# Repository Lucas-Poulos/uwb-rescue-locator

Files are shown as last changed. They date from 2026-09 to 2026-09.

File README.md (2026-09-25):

# UWB Rescue Locator

Repo: https://github.com/Lucas-Poulos/uwb-rescue-locator

A two-board UWB positioning system for a rescue/safety use case: a
**wristband** worn by a person, and a fixed **bay station** that locates it
in 3D from four anchor points and reports it over Bluetooth LE to a nearby
laptop.

Positioning is a **hybrid of two-way ranging and TDoA**, not symmetric
multilateration. A center anchor ranges to the tag for distance; three outer
anchors timestamp the same tag transmission and give direction from the
arrival-time differences. The four anchors are **not interchangeable** --
see [`docs/positioning.md`](docs/positioning.md), which is the document to
read first if you're working on anchors, clocking, coax, or connectors.

## Getting started (new contributor setup)

### 1. Install KiCad

The team standard is **KiCad 10.0.5** (see Toolchain below for why).

- **macOS**: `brew install --cask kicad` (Homebrew). If KiCad is already
  installed some other way, add `--force` to overwrite it.
- **Windows/Linux**: download the installer for your platform from
  https://www.kicad.org/download/.

You do **not** need to set any environment variables or configure library
paths yourself -- both boards' `fp-lib-table`/`sym-lib-table` use
`${KIPRJMOD}`-relative paths into this repo's own `shared/` and `libs/`
folders, so cloning the repo anywhere and opening a project just works.

The very first time you launch the KiCad GUI on a given machine, it may
offer to set up its own default global libraries (Device, Connector, etc.)
-- accept the defaults. This is a one-time, per-machine, KiCad-level setup
step, unrelated to this repo.

### 2. Get repo access and clone it

Ask whoever's administering the repo to add you as a collaborator (repo
link at the top of this file), then:

```
git clone git@github.com:Lucas-Poulos/uwb-rescue-locator.git
cd uwb-rescue-locator
```

(Use the HTTPS clone URL instead if you haven't set up an SSH key with
GitHub.)

### 3. Open a board

KiCad doesn't support one project spanning multiple PCBs, so open whichever
board you're working on directly -- there's no single top-level project
file for the whole repo:

```
open wristband/wristband.kicad_pro       # macOS; or just double-click the file
open bay-station/bay-station.kicad_pro
```

### 4. Sanity-check your setup

From a terminal, **outside** this repo (see the `kicad-cli` gotcha further
down for why):

```
cd /tmp
kicad-cli sch erc /path/to/uwb-rescue-locator/wristband/wristband.kicad_sch
```

If this reports a handful of known/expected items (see each board's sheet
table below) rather than a wall of "library not included in configuration"
errors, your KiCad install is set up correctly. If you do see that wall of
errors, see the per-major-version global library table note in Toolchain.

Before pushing anything, also read `CONTRIBUTING.md` -- branch off `main`,
don't edit a sheet someone else is actively working on, and PRs need review
(branch protection is on).

## Status (last updated 2026-09-19)

**Schematic capture is in progress on both boards. Nothing is wired yet
except each board's own Power/BMS sheet.** If you're an agent or a new
teammate picking this up cold, read this whole section before touching
anything -- it's written to be a complete handoff.

> ### Architecture change in flight: the bay station's anchors
>
> The positioning scheme was specified properly for the first time on
> 2026-09-19 (`docs/positioning.md`), and it invalidates how the bay
> station's UWB anchors are currently drawn. **Target: 10-30 cm accuracy at
> ~10 m, on Channel 5 (6489.6 MHz).**
>
> What the schematic gets wrong today:
>
> 1. **The four anchors are drawn as interchangeable peers.** They aren't --
>    one is a center anchor doing two-way ranging, three are outer anchors
>    doing TDoA against it.
> 2. **The antennas are on the board.** TDoA bearing accuracy scales with
>    baseline; a board-sized baseline gives ~17 degrees of bearing error.
>    The four antennas move onto ~1-2 m coax runs to a rigid frame.
> 3. **The DWM3000 module can't do TDoA in a multi-anchor array at all.** It
>    exposes no clock pin, so four of them cannot share a time base -- and
>    1 ns of clock error is 30 cm of position error.
>
> **The resolved architecture:** four discrete **DW3210** ICs on the one PCB,
> sharing a single 38.4 MHz TCXO through a 1:4 low-skew buffer, with the four
> antennas remote on coax. This makes synchronization *structurally absent*
> rather than solved -- no drift model, no sync firmware -- and moves the cost
> into the RF path, where CH5's ~17 dB of link margin absorbs it.
>
> Going discrete adds an RF front-end and a controlled-impedance stackup. It
> also loses the module's pre-certified status -- which **does not matter
> here**: this is a university prototype, not marketed or sold, so it doesn't
> go through FCC/CE testing. That was the single largest cost of going
> discrete, and it's now off the table. See `docs/decisions.md`.
>
> The remaining critical-path item is **array calibration**, which the design
> genuinely does not close without.
>
> **The wristband is unaffected by the clock problem** -- a single transceiver
> has nothing to synchronize against. It has separately consolidated onto a
> single DWM3001C; see its own README.

### What exists, per board

The wristband has 7 hierarchical sheets, the bay station 10. Reference designators are
project-wide unique per board (checked, no collisions) -- see each
`libs/components.csv` for the full part-by-part BOM.

**Wristband** (`wristband/`):
| Sheet | Status | Contents |
|---|---|---|
| Power BMS | **Wired** (global labels, no drawn wires), ERC clean (0 errors, 1 cosmetic warning) | JST-PH battery -> AO3401A reverse-polarity FET -> TVS -> DW01A+FS8205A protection -> MCP73831 charger (USB-C in) |
| Radio MCU | Placement only, not wired | DWM3001C (U3) + decoupling. One module: DW3110 UWB + nRF52833 MCU + accelerometer + both antennas |
| Mechanical | Placement only | 4x M2 mounting holes |
| Regulation | Placement only, not wired | MCP1700T-3302E/TT LDO (3.3V) -- battery hits 4.2V, DWM3001C tops out at 3.6V |
| Programming/Debug | Placement only, not wired | ARM Cortex Debug SWD header, targeting the nRF52833 inside U3 |
| Indicators | Placement only | Status LEDs: D2 charge (MCP73831 STAT) + D3 system (nRF52833 GPIO) |
| Test Points | Placement only, **new** | TP1-TP5: both rails, 2x GND, firmware timing marker |

**Bay Station** (`bay-station/`):
| Sheet | Status | Contents |
|---|---|---|
| Power BMS | **Wired** (global labels), ERC has 8 known/expected items (see `power_bms_notes.md`) | Barrel jack + USB-C power-only input -> MCP73871 power-path charger -> MAX17048 fuel gauge; separate backup-battery input with its own AO3401A reverse-polarity FET + TVS |
| Connectivity | Placement only, not wired | Fanstel BT840 (U3, nRF52840) + decoupling. Symbol authored from the real datasheet |
| UWB Array | Placement only, not wired | 4x DW3210 (U4=A0 center, U5-U7=A1-A3 outer) + GPIO5/6 straps (R10-R17) + IRQ pulldowns (R25-R28) |
| Mechanical | Placement only | 4x M3 mounting holes |
| Regulation | Placement only, not wired | TPS62A02PDDCR buck converter -- steps the unregulated `+VSYS` rail down to a safe ~3.3V for the BT840 host and the DW3210 anchors |
| Clock Distribution | Placement only, **new** | Shared 38.4MHz reference for the 4x DW3210 array: AC-coupling + XTO caps placed, TCXO/buffer TBD |
| Indicators | Placement only | Status LEDs: D4 charging, D5 charge-done, D6 power-good (all MCP73871), D7 system (host GPIO) |
| Test Points | Placement only | TP1-TP14: rails, 2x GND, TCXO + 4x anchor clock, SPI, IRQ, reset |
| GNSS / Orientation | Placement only, **new** | MAX-M10S GNSS (U9) + LIS3MDL magnetometer (U10) + LIS2DH accelerometer (U11) -- georeferences the array |
| Programming/Debug | Placement only | **Rebuilt for Nordic**: SWD header (J3) + RESET button (SW2). ESP32 circuitry and the second USB-C deleted |

"Placement only" sheets deliberately show a lot of ERC "not connected"/"not
driven" warnings -- that's expected, not a bug, until they get wired.

### Confirmed chips/ICs (all sourced against real datasheets, not guessed)

| Part number | Role | Board(s) | Qty |
|---|---|---|---|
| Qorvo **DWM3001C** | UWB transceiver + nRF52833 MCU + LIS2DH12 accelerometer + both antennas, one module. Replaced NINA-B111 + DWM3000 + the antenna sheet | Wristband | 1 |
| Qorvo **DW3210** | Discrete UWB transceiver IC, QFN-40 5x5mm. One per anchor (U4=A0 center, U5-U7=A1-A3 outer). Chosen over the DWM3000 module because the module exposes no clock pin, and a shared reference is what makes the TDoA array work -- see `docs/positioning.md` | Bay Station | 4 |
| Qorvo **DWM3000** | UWB transceiver module. **No longer used on either board** -- the wristband moved to the DWM3001C and the bay station to discrete DW3210. Symbol and footprint are retained in `shared/` for reference only | -- | 0 |
| Microchip **MCP73831** | LiPo linear battery charger | Wristband | 1 |
| Fortune Semiconductor **DW01A** | Battery protection IC | Wristband | 1 |
| Fortune Semiconductor **FS8205** (commonly sold as "FS8205A" -- see `wristband/libs/README.md`) | Protection dual MOSFET, DW01A's partner IC | Wristband | 1 |
| AOS **AO3401A** | Reverse-battery-polarity protection P-MOSFET ("ideal diode") | Wristband + Bay Station | 2 |
| onsemi **ESD5B5.0ST1G** | TVS diode, battery/power-input protection | Wristband (1) + Bay Station (2) | 3 |
| Fanstel **BT840** (Nordic nRF52840) | Host MCU + BLE link to a laptop. Replaced ESP32-S3-WROOM-1 once the WiFi/internet requirement was dropped | Bay Station | 1 |
| Microchip **MCP73871** | Charge management + power-path IC | Bay Station | 1 |
| Maxim/Analog Devices **MAX17048** | Battery fuel gauge (SOC monitor) | Bay Station | 1 |
| Microchip **MCP1700T-3302E/TT** | LDO regulator (3.3V) -- battery rail can hit 4.2V, which exceeds the DWM3001C's 3.6V operating max without this | Wristband | 1 |
| TI **TPS62A02PDDCR** | Buck (switching) regulator -- same voltage-safety role as the wristband's LDO, sized for the bay station's higher combined load current | Bay Station | 1 |

Footprint caveats: MAX17048 is flagged `_PLACEHOLDER` in its footprint file
-- pin/electrical data is fully verified, but one land-pattern dimension
needs re-checking against the real datasheet figure before fab (see
`bay-station/libs/README.md`). The same caveat applies to the DWM3000
footprint retained in `shared/`, though nothing uses it now.

**No footprint assigned yet**: `U3` on both boards (BT840, 65 pins; and
DWM3001C, 48 pins), plus bay-station `L1` (1uH inductor -- no exact KiCad
default matches the XGL3520, pick at BOM time) and `SW2`. Not blocking
while both `.kicad_pcb` files are still empty, but it blocks layout.

Standard passive size for this whole project: **0603** for R/C/L (0-ohm
0603 link/jumper resistors are documented as a standard available option in
each `components.csv`, not yet placed on any sheet -- no specific
strap/bridge need identified yet).

Full reasoning/history for every choice above, plus the still-open
decisions (anchor placement, uplink backend, etc.), is in
`docs/decisions.md`.

### Known gotchas for whoever (human or agent) works on this next

- **kicad-cli silently fails on `extends`-based symbols.** Any cached
  schematic symbol using KiCad's `extends` mechanism (e.g. the default
  `AO3401A extends TP0610T`) makes `kicad-cli` fail to load the *entire
  file* and silently report it as empty (0 components, 0 ERC violations)
  rather than erroring loudly. Both boards work around this by embedding a
  flattened, non-`extends` copy of AO3401A. If a future sheet adds another
  `extends`-based part and ERC suspiciously shows 0 violations, check this
  first.
- **Always run `kicad-cli` from a scratch directory, never from inside a
  git repo.** It writes `.rpt` report files to the current working
  directory as a side effect; running it from inside a repo pollutes that
  repo's working tree with stray files.
- **KiCad's global library table is per-major-version and doesn't
  auto-populate from `kicad-cli` alone** -- see the Toolchain section below.
- **Don't leave a KiCad GUI window open on a project while also editing its
  files by hand/via script.** This happened once already: a background GUI
  session silently resaved `bay-station/power_bms.kicad_sch` in KiCad 10
  format while a concurrent edit was adding new sheets to the root file. No
  data was lost (verified via a reference-designator diff before
  committing), but it could have silently clobbered the newer edits if the
  stale window had been saved again afterward. Close/reload any open KiCad
  windows before doing further programmatic edits, and vice versa.
- The sibling project at `~/kicad-projects/wristband-alarm` (a *different*,
  unrelated wristband-alarm concept, also u-blox NINA-based) has its own
  long-standing uncommitted working-tree state -- don't touch it, don't
  assume its README reflects its actual working tree.

### Not done yet (in rough next-up order)

1. **Bay station: rework the anchor design** for four discrete DW3210s on
   one board sharing a TCXO, with the antennas on coax. Blocked behind the
   open items in `docs/decisions.md` (cable loss, TCXO/buffer selection,
   array calibration) -- this is the project's critical path.
2. Wire all placement-only sheets (net labels between MCU/radio pins, their
   decoupling, the new regulator outputs, and power-rail connections in
   from Power BMS). The wristband can proceed independently of item 1.
3. ~~**Bay station: resolve the two-USB-C-connector situation**~~ -- resolved
   by the move to Nordic. The second connector existed only for ESP32-S3
   native-USB flashing; the BT840 programs over SWD, so it goes away with the
   rest of the ESP32-specific circuitry.
4. **Bay station: source a real footprint for L1** (the buck converter's
   inductor, Coilcraft XGL3520-102MEC) -- no KiCad-default match exists yet.
5. ~~Confirm/re-verify decoupling cap values against each part's exact
   datasheet application circuit~~ -- done, see `docs/passives-reference.md`.
   One passive was found missing (100k IRQ/GPIO8 pulldowns, now added to all
   5 DWM3000 instances); DWM3000's own decoupling was confirmed to exceed
   what Qorvo's minimal example circuit actually calls for (kept anyway, not
   wrong, just more conservative than strictly required).
6. ~~Antenna matching-network values~~ -- gone. The DWM3001C carries both
   antennas on-module, so `antenna.kicad_sch` was deleted along with the
   tuning task.
7. ~~Anchor placement/enclosure geometry~~ -- topology resolved (all four
   transceivers on-board, antennas remote on coax to a rigid frame, see
   `docs/positioning.md`); the remaining piece is the frame's mechanical
   design, including A0's out-of-plane offset.
8. Bay station uplink protocol -- what the laptop actually receives over BLE
   (open decision). "Backend" no longer applies: there is no server, see
   `docs/system-overview.md`.
9. PCB layout. The bay station's `.kicad_pcb` now has its **4-layer
   controlled-impedance stackup** set from DW3000 Section 7.3.2 Figure 35
   (1.048mm finished) -- but nothing else: no footprints, no outline. The
   wristband's is still an empty stub. The blocker is upstream of layout:
   both boards are placement-only, so there are **zero nets** to import.

## System overview

```
                         A1 ← antenna on coax
                            \
   ┌─────────────┐           \      ┌───────────────────────────┐
   │  Wristband   │  UWB       ○────│  Bay Station (ONE PCB)     │
   │  (worn tag)  │ ═════════▶ A0   │  4x DW3210, one TCXO       │
   └─────────────┘  one TX    / \   │  BT840 (nRF52840) host     │
                             /   \  └───────────┬────────────────┘
                           A2     A3            │ Bluetooth LE
                      antennas on ~1-2 m        ▼
                      coax, rigid frame       Laptop

   A0     two-way ranging  -> range to tag
   A1-A3  TDoA vs. A0      -> direction to tag

   All four transceivers share one clock on the board.
   Only the antennas are remote.
```

- **Wristband**: one Qorvo DWM3001C (UWB + nRF52833 MCU + antennas) +
  a compact BMS (MCP73831 charger + DW01A/FS8205 protection + AO3401A
  reverse-polarity protection). Design compromises favor small size and
  just enough battery life to get core functionality working. In the
  positioning scheme its job is simply to transmit -- one transmission
  yields all four measurements, deliberately, because the tag is the
  power-constrained side.
- **Bay station**: four UWB receivers in two roles (one center, three outer)
  on a single PCB sharing one TCXO + a Fanstel BT840 (nRF52840) host, linking
  to a laptop over BLE + a BMS designed for long runtime rather than small size
  (MCP73871 power-path charger + MAX17048 fuel gauge), since the bay station
  isn't worn. The four antennas sit on ~1-2 m coax runs to a rigid frame --
  that's what buys the baseline the bearing measurement needs.

There's no physical connector between the wristband and the bay station --
their only interface is the UWB radio link. The bay station's own antennas
are wired to it over SMA coax (CH5 at 6489.6 MHz is above U.FL's 6 GHz
rating). See `docs/system-overview.md` and `docs/positioning.md`.

## Repo layout

```
shared/                      # symbols/footprints/3D models used on BOTH boards (e.g. the UWB IC)
  symbols/                   # shared .kicad_sym library
  footprints/                # shared .pretty footprint library
  3dmodels/                  # shared .step/.wrl models
wristband/                   # KiCad project: the wearable tag
  wristband.kicad_pro/sch/pcb
  libs/                      # wristband-only symbols/footprints
bay-station/                 # KiCad project: the fixed 4-anchor station
  bay-station.kicad_pro/sch/pcb
  libs/                      # bay-station-only symbols/footprints
docs/
  positioning.md             # the ToF + TDoA scheme, error budget, clock architecture
  system-overview.md         # block diagram + RF/data interface between the boards
  decisions.md               # open + resolved component/architecture decisions log
  passives-reference.md      # every chip's reference-design passives, compiled per-chip
  bom-cost.md                # build cost estimate for one prototype pair
firmware/                    # nRF52840 / nRF52833 firmware -- skeleton only, nothing written
CLAUDE.md                    # working rules for Claude Code / other coding agents
CONTRIBUTING.md              # git workflow, sheet conventions, pre-push checks
```

Each board is its own KiCad project (KiCad doesn't support one project
spanning multiple PCBs), but both live in this one repo so shared parts,
docs, and history stay in one place. Each project's `fp-lib-table` /
`sym-lib-table` reference the `shared/` libraries via `${KIPRJMOD}` relative
paths, so this works regardless of where the repo is cloned -- no per-machine
setup needed.

## Toolchain

Files are currently in **KiCad 8.0** format, originally authored/verified
against KiCad 8.0.6. As of 2026-08-14 this machine has been upgraded to
**KiCad 10.0.5** (the actual current stable -- confirmed as the team's
standard, superseding an earlier, since-corrected plan to target KiCad 9.x).
All existing files were re-checked with
`kicad-cli` under 10.0.5 (`sch erc`/`pcb drc`) and open/parse cleanly with no
new issues -- opening a file in the newer GUI and re-saving is still a
one-way, zero-cost upgrade whenever the team wants to bump the file format
itself; nothing has been re-saved yet, so the files on disk are still 8.0
format.

Note for anyone else upgrading KiCad's major version: `kicad-cli` alone
won't auto-populate the new version's global symbol/footprint library table
(`~/Library/Preferences/kicad/<version>/sym-lib-table` /`fp-lib-table`) --
that normally happens the first time you launch the actual KiCad GUI and it
offers to migrate/create settings. If you only ever use `kicad-cli`
headlessly without opening the GUI first, you may see a wall of spurious
"library not included in configuration" ERC errors -- just launch KiCad.app
once (or copy the two `*-lib-table` files from
`.../KiCad.app/Contents/SharedSupport/template/`) to fix it.

## Using Claude Code (or another coding agent) on this project

**The working rules for agents live in [`CLAUDE.md`](CLAUDE.md)** -- Claude
Code picks that up automatically. This section is the human-readable version
of why those rules exist.

KiCad's file formats (`.kicad_sch`, `.kicad_pcb`, `.kicad_pro`, `.kicad_sym`,
`.kicad_mod`) are plain text (S-expression or JSON) -- an agent can read and
edit them directly like any other source file, no special MCP server or
plugin required. Everything in this repo so far was built that way. A few
things make it work reliably, several of them learned the hard way in this
repo's own history:

- **`kicad-cli` is the fast headless sanity check.** After any edit, run
  `kicad-cli sch erc <board>.kicad_sch` and `kicad-cli pcb drc
  <board>.kicad_pcb` before trusting a change.
  - **macOS**: a Homebrew install symlinks it onto `PATH` automatically
    (`/opt/homebrew/bin/kicad-cli`); otherwise it's inside the app bundle at
    `/Applications/KiCad/KiCad.app/Contents/MacOS/kicad-cli`.
  - **Windows**: the official installer puts it on `PATH` automatically; if
    not, it's at `C:\Program Files\KiCad\10.0\bin\kicad-cli.exe`.
  - **Linux**: on `PATH` automatically via most package managers (apt,
    dnf, etc.) or the official AppImage/flatpak.
- **Always run `kicad-cli` from a scratch/temp directory, never from
  inside this repo.** It writes `.rpt` report files to the current working
  directory as a side effect -- running it from inside a git repo (this
  one or any other) pollutes the working tree with stray files. This has
  actually happened once already, to an unrelated sibling project, from a
  leftover `cd`.
- **`kicad-cli` silently fails on `extends`-based symbols.** A cached
  schematic symbol using KiCad's `extends` mechanism (e.g. the default
  library's `AO3401A extends TP0610T`) makes `kicad-cli` fail to load the
  *entire file* and report it as empty (0 components, 0 ERC violations)
  instead of erroring loudly -- a suspiciously clean ERC run is a red flag,
  not necessarily good news. This repo works around it everywhere by
  embedding flattened, non-`extends` copies of any such symbols (see
  `docs/decisions.md` and the various `*_notes.md` files for examples).
- **Use an existing sheet/symbol/footprint as the format template before
  writing a new one.** Every file in this repo was built by reading a
  known-good file first -- either one already in this repo, or one of
  KiCad's own bundled default libraries -- and matching its exact
  structure, rather than freehand-authoring the s-expression format from
  memory. This repo uses literal tab characters for indentation, not
  spaces; match that.
- **Don't run scripted file edits at the same time as a live KiCad GUI
  session has the same project open.** A background GUI window doesn't
  know about changes made outside it, and saving from a stale window can
  silently overwrite newer edits -- this already caused one near-miss on
  the bay station board (see "Known gotchas" above). Close/reload any open
  KiCad windows before scripted edits, and vice versa. A lock file at
  `<board>/~<board>.kicad_pro.lck` means a GUI session currently has that
  project open.
- **Verify real datasheet facts (pinouts, voltage ratings, current draw)
  by actually fetching and reading the datasheet PDF**, not from memory or
  a search-result summary -- several real bugs/gaps in this repo were only
  caught this way (e.g. the wristband's missing voltage regulator, a
  part-number that doesn't actually exist, a mislabeled SOT-23-6 part).
- **pcbnew's Python bindings** are available for programmatic
  footprint/board work (generating a blank `.kicad_pcb`, loading a
  footprint to sanity-check its pad count, etc.) via KiCad's own bundled
  Python interpreter -- **not** your system Python, which won't have the
  `pcbnew` module installed:
  - **macOS**: `/Applications/KiCad/KiCad.app/Contents/Frameworks/Python.framework/Versions/Current/bin/python3`
  - **Windows**: typically `C:\Program Files\KiCad\10.0\bin\python.exe`
  - **Linux**: usually just your system `python3` if KiCad was installed via
    a package manager that wires up the `pcbnew` module for it; otherwise
    check your distro's KiCad packaging docs.

## Will this work on both Mac and Windows?

Yes, and this has actually been checked, not just assumed:

- No absolute Mac-specific paths are baked into any `.kicad_pro`/`.kicad_sch`/
  `.kicad_pcb`/library file (`git grep`-checked) -- all cross-file/library
  references use `${KIPRJMOD}`-relative paths, which KiCad resolves
  identically on every OS.
- No filenames in this repo use characters or reserved names that are
  illegal on Windows (`: * ? " < > |`, or `CON`/`PRN`/`AUX`/`NUL`/`COM1-9`/
  `LPT1-9`), and no path exceeds even a fraction of Windows' historical
  260-character path limit (longest path in this repo is 80 characters).
- All tracked files use consistent LF line endings, and `.gitattributes`
  normalizes this going forward so a Windows contributor's git config
  (which sometimes auto-converts line endings on checkout) can't silently
  turn KiCad files into CRLF and create noisy diffs or merge pain.

What differs by platform is purely the install step and a couple of tool
paths (both covered above/in Getting Started) -- KiCad itself, the file
formats, and this repo's structure are fully cross-platform.

## Contributing

See `CONTRIBUTING.md` for the git workflow (branching, hierarchical-sheet
conventions to avoid merge conflicts, pre-push checks).

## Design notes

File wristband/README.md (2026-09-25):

# Wristband

The worn tag. Open `wristband.kicad_pro` in KiCad.

## Scope

Deliberately minimal: **battery management plus one UWB module, and not much
else.** The tag's only job is to take part in a two-way ranging exchange with
the bay station's center anchor. Everything not needed for that is gone.

- **UWB + MCU**: Qorvo **DWM3001C** (resolved 2026-09-19) -- one module
  containing the DW3110 UWB transceiver, a Nordic nRF52833 MCU, an ST
  LIS2DH12 accelerometer, the UWB and Bluetooth antennas, power management
  and the 38.4 MHz crystal. Its datasheet states it *"requires no RF design
  as the antenna and associated analog and RF components are on the module"*.
- **BLE and the accelerometer are unused.** The tag talks only over UWB. Both
  are silicon inside a module bought for its Cortex-M4 and its UWB radio --
  they cost nothing to leave idle: no external parts, no wiring, no firmware.
  See "Worth revisiting" below.
- **BMS**: sized for "just enough" runtime -- size and weight take priority
  over battery life here, in contrast with the bay station.

Why the tag transmits once per fix: the bay station's center anchor completes
the ranging exchange, and the three outer anchors timestamp that *same*
transmission. One transmission, four measurements -- deliberately, because
the tag is the power-constrained side. See `../docs/positioning.md`.

## Status

Seven hierarchical sheets, all registered in `wristband.kicad_pro`'s `sheets`
list and wired into `wristband.kicad_sch` as sheet symbols.

| Sheet | Status | Contents |
|---|---|---|
| `power_bms` | **Wired** (global labels, no drawn wires), ERC clean | Full battery/charging/protection chain |
| `radio_mcu` | **Wired**, ERC clean | DWM3001C (U4) + decoupling; SWD, RESET_N, SWO, VBAT_SENSE, SOS button |
| `regulation` | **Wired**, ERC clean | TPS7A0233PDBVR LDO -> 3.3V (U5) |
| `programming_debug` | **Wired**, ERC clean | ARM Cortex Debug SWD header |
| `indicators` | Placement only -- **8 ERC errors** (unconnected pins) | Status LEDs D2 (charge) + D3 (system) |
| `testpoints` | Placement only -- **5 ERC errors** (unconnected pins) | TP1-TP5: both rails, 2x GND, firmware timing marker |
| `mechanical` | Placement only | 4x M2 mounting holes |

**"Placement only" means components are instantiated and laid out, but
nothing is wired** -- no drawn wires, no global labels, no net identity.

`indicators` and `testpoints` are the two sheets still in that state. They
came across from the positioning-architecture redesign on `main`, where they
were never wired, and they account for all 13 of the wristband's remaining
ERC errors. Everything else on this board is wired and ERC clean.

**ERC, run 2026-09-19 with kicad-cli 10.0.6: 104 violations, ZERO errors.**
All warnings, and all the expected unwired-sheet state: 80 pin_not_connected,
10 power_pin_not_driven, 3 pin_not_driven, plus 11 lib_symbol_mismatch from
the embedded 8.0-format symbol copies differing from the 10.x libraries
(pre-existing and by design -- see the flattened-copy workaround in
`../CLAUDE.md`). DRC reports one violation per board, `invalid_outline`,
because no board outline is drawn yet.

### Sheet detail

- **`power_bms.kicad_sch`** -- the complete battery chain: 2-pin JST-PH
  battery input (`BT1`); AO3401A P-MOSFET reverse-polarity "ideal diode"
  (`Q1`, `R1`); battery-rail TVS ESD5B5.0ST1G (`D1`); DW01A + FS8205A
  single-cell overcharge/overdischarge/overcurrent protection wired per
  Fortune Semiconductor's own DW01A typical application circuit (`U1`, `Q2`,
  `R2`, `R3`, `C1`); MCP73831 Li-Po charger with power-only USB-C input, PROG
  resistor sized for ~147mA charge current, and datasheet-recommended
  input/output caps (`U2`, `J1`, `R4`, `C2`, `C3`, `R5`, `R6`); bulk/bypass
  decoupling on the protected `VBAT` rail (`C4`, `C5`).

  Net identity is carried entirely by global labels placed on top of each
  pin. ERC: 0 errors, 1 harmless documented warning. Full rationale in
  `power_bms_notes.md`.

- **`radio_mcu.kicad_sch`** -- one `wristband:DWM3001C` (`U4`) plus VDD
  decoupling (`C6` 100nF, `C7` 10uF). Now wired: SWD (`SWDCLK`/`SWDIO`/
  `SWO`), `RESET_N`, `VBAT_SENSE` on P0.02/AIN0, and the SOS button on
  P0.17. 12 of the module's 48 pins are tied; the rest await the pin
  assignments still open in `../docs/decisions.md`.

  Pin data verified against the real Qorvo DWM3001C Data Sheet Rev B (May
  2022), Table 2. One caveat carried in the symbol: **pin 18 is not
  documented in that table** (it lists 1-17 and 19-48), so it is modelled as
  a passive NC and needs confirming against the land-pattern figure.

  Decoupling values are conservative standard practice, *not*
  datasheet-specified -- the module has on-board power management and Qorvo
  publishes no external application circuit for it.

  Two real layout requirements are recorded in the sheet's own notes: the
  **10 mm antenna keep-out** (Section 7.1) and **keeping the module at least
  1 cm from the PCB edge** (Section 7.2), which reduces the horizontally
  polarized radiation component and improves multipath resilience.

- **`regulation.kicad_sch`** -- TI **TPS7A0233PDBVR** LDO (`U5`, SOT-23-5,
  3.3V fixed, 200mA, 25nA typ Iq) steps the protected `VBAT` rail (up to
  4.2V at full charge) down to `+3V3`. Replaced the MCP1700T-3302E/TT on
  2026-09-23, whose 1.6uA Iq had become the board's largest standby draw --
  see `../docs/decisions.md`. Still required: the DWM3001C's operating
  maximum is 3.6V (Table 4), well under a full battery. **EN must be tied
  high**; the part is disabled when EN floats. See `regulation_notes.md`.

- **`programming_debug.kicad_sch`** -- ARM Cortex Debug SWD connector (`J3`,
  `Connector:Conn_ARM_JTAG_SWD_10`, 2x5 1.27mm). Now targets the nRF52833
  inside U3, via `SWD_CLK` (pin 2) and `SWD_DIO` (pin 3).

- **`indicators.kicad_sch`** -- status LEDs. `D2`/`R10` is charge status from
  MCP73831 `STAT` (U2 pin 1, `power_bms.kicad_sch`). `D3`/`R11` is system
  status on an nRF52833 GPIO. 0603 parts, indicative 1k series resistors,
  low-current by design since the tag runs off a small cell.

- **`testpoints.kicad_sch`** *(new)* -- `TP1` +3V3, `TP2` VBAT, `TP3`/`TP4`
  ground, `TP5` a firmware timing marker on a spare nRF52833 GPIO so tag-side
  exchange timing is visible on a scope. Deliberately minimal: the DWM3001C's
  internals are unreachable and SWD already comes out on `J3`. `TP2` matters
  because there is no power switch -- it is the only way to check the battery
  chain without disconnecting the cell.

- **`mechanical.kicad_sch`** -- 4x M2 mounting holes (`H1`-`H4`).

### Next up

1. **Get U3's footprint.** Do not hand-author it -- import from a vendor
   library. Qorvo supplies DWM3001C footprint/symbol files (Altium format)
   via their UWB tech forum, and SnapMagic/SnapEDA lists a Qorvo-provided
   set. Check pad naming matches this symbol's 1-48 numbering. Blocks layout.
2. Wire the six placement-only sheets: the `VBAT` -> `+3V3` rail handoff,
   SWD to U3, the LED drives. There is no MCU-to-transceiver SPI to wire any
   more -- that link is inside the module.

### Worth revisiting

**Motion-gating the UWB.** The LIS2DH12 accelerometer inside the DWM3001C is
unused, but the tag is the power-constrained side of the whole system. Only
ranging when the wearer actually moves is the largest battery lever available
and costs nothing in hardware -- the accelerometer is already on the module's
I2C bus (pins 14/15). Worth doing once basic ranging works.

## Libraries

- `libs/` -- wristband-only symbols/footprints, including the hand-authored
  `DWM3001C` symbol
- `../shared/` -- still registered via `fp-lib-table`/`sym-lib-table`, but
  this board no longer uses anything from it (see `../shared/README.md`)

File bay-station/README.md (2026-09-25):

# Bay Station

The fixed reference station. Open `bay-station.kicad_pro` in KiCad.

## Scope

- **UWB anchors**: four DW3210 transceivers, all on this PCB sharing one
  38.4 MHz TCXO, in two distinct roles -- one **center** anchor (A0) that
  does two-way ranging with the wristband, and three **outer** anchors that
  measure TDoA against it. Range plus direction gives a 3D fix. The four
  **antennas** are remote, on ~1-2 m SMA coax runs to a rigid frame. Read
  `../docs/positioning.md` before touching anything in the anchor, clock,
  coax, or connector path.
- **Host MCU + link**: Fanstel **BT840** (Nordic nRF52840, resolved
  2026-09-19) -- drives the four DW3210s and reports position over **BLE to a
  nearby laptop**. There is no internet uplink; that was dropped deliberately,
  and dropping it is what allowed the move off the ESP32-S3 to Nordic. See
  `../docs/decisions.md`.
- **BMS**: optimized for longevity rather than size, since this board isn't
  worn (contrast with the wristband's compromise-heavy BMS).

Target performance: **10-30 cm at ~10 m, on Channel 5 (6489.6 MHz)**.

> **Schematic capture is done for the anchor array; layout is not.** Four
> discrete DW3210s share one TCXO through a 1:4 low-skew buffer, with the
> antennas on ~1-2 m coax. What remains before layout: footprints for the
> BT840 and the DW3210 exposed pad, TCXO and buffer part selection, and the
> anchor decoupling, which must be re-derived for a bare IC rather than
> reused from the module.
>
> **Array calibration is a deliverable, not a bring-up nicety** -- the design
> does not meet its accuracy target without it. See `../docs/decisions.md`.

## Status

Ten hierarchical sheets, all registered in `bay-station.kicad_pro`'s
`sheets` list and wired into `bay-station.kicad_sch` as sheet symbols.

| Sheet | Status | Contents |
|---|---|---|
| `power_bms` | **Wired** (global labels), 8 known/expected ERC items | Barrel jack + USB-C in -> MCP73871 power-path -> MAX17048 gauge |
| `connectivity` | Placement only | **BT840 (U3) placed** + C5/C6/C7 decoupling. Symbol authored; footprint still needed |
| `uwb_array` | Placement only | **4x DW3210 placed** (U4=A0 center, U5-U7=A1-A3 outer) + R10-R17 straps + R25-R28 IRQ pulldowns |
| `regulation` | Placement only | TPS62A02PDDCR buck -> +3V3_SYS |
| `programming_debug` | Placement only | **Rebuilt for Nordic**: SWD header (J3) + RESET button (SW2). ESP32 circuitry and the second USB-C deleted |
| `clock_dist` | Placement only, **new** | Shared 38.4MHz reference: AC-coupling + XTO caps placed, TCXO/buffer TBD |
| `indicators` | Placement only, **new** | Status LEDs D4-D7 (charge, charge-done, power-good, system) |
| `testpoints` | Placement only, **new** | TP1-TP14: rails, 2x GND, TCXO + 4x anchor clock, SPI, IRQ, reset |
| `gnss` | Placement only, **new** | MAX-M10S GNSS (U9) + LIS3MDL magnetometer (U10) + LIS2DH accelerometer (U11) |
| `mechanical` | Placement only | 4x M3 mounting holes |

**"Placement only" means components are instantiated but nothing is wired**
-- no wires, no global labels.

**ERC, re-run 2026-09-23 with kicad-cli 10.0.6: 518 violations, ZERO errors.**
All warnings: 360 pin_not_connected, 98 power_pin_not_driven, 36
pin_not_driven, 9 lib_symbol_mismatch, 8 ground_pin_not_ground (the DW3210
VSS pins, which resolve once grounds are wired), 6 isolated_pin_label (the
MCP73871 status outputs, which `indicators` will terminate), and 1
lib_symbol_issues on U8 -- investigated and deliberately left alone, see
`../docs/decisions.md`. DRC reports one `invalid_outline`, because no board
outline is drawn yet.

### The PCB

`bay-station.kicad_pcb` now carries the **4-layer controlled-impedance
stackup** (F.Cu / prepreg 254um / In1.Cu / core 400um / In2.Cu / prepreg
254um / B.Cu, 35um copper throughout, 1.048mm finished), taken from DW3000
Datasheet v1.3 Section 7.3.2 Figure 35. Until 2026-09-23 the file was an
empty 2-layer default stub, which contradicted a decision the docs had
already recorded as settled. The rest of Section 7.3 -- 50 ohm RF1/RF2,
ground cutouts under each DW3210, group separation -- is written as a note
on the board's `Cmts.User` layer, where layout will actually see it.

The dielectric numbers (er 4.5, tan d 0.02) are KiCad's FR4 defaults, not
datasheet values. Controlled impedance means the fab's stackup wins.

**Nothing else is on the board.** No footprints are placed and no outline is
drawn, and neither is worth doing yet: every sheet is still placement-only,
so `kicad-cli sch export netlist` returns **zero nets**. Importing footprints
now would give an unconnected pile with no ratsnest to place against. Wire
the sheets first.

Three parts also could not be placed even if it were wired, because they
have no footprint assigned: **L1** (no exact KiCad match for the Coilcraft
XGL3520), **U3** (BT840, awaiting a vendor import) and **SW2** (RESET button,
never assigned one -- newly found). See `../docs/decisions.md`.

### Sheet detail

- **`power_bms.kicad_sch`** -- external power input via DC barrel jack
  (`Connector:Barrel_Jack`, series Schottky reverse-polarity diode) and a
  power-only USB-C receptacle (`Connector:USB_C_Receptacle_PowerOnly_6P`,
  CC1/CC2 5.1k pulldowns), both feeding a shared `+5V_IN` net with its own
  TVS. Backup Li-Ion cell gets an AO3401A P-MOSFET reverse-polarity "ideal
  diode" plus its own TVS. MCP73871 charge-management/power-path IC wired per
  Microchip's typical application circuit (DS20002090E) in
  AC-DC-adapter/power-path mode (SEL=high), PROG1/PROG3 set for a 500mA
  fast-charge / 50mA termination profile, plus the VPCC power-path-priority
  divider, THERM NTC, and IN/OUT/VBAT decoupling. MAX17048 fuel gauge
  (`bay_station:MAX17048G+T10`) with VDD decoupling, CTG/QSTRT tied per
  datasheet, ALRT/SCL/SDA brought out via global labels.

  ERC-clean except one deliberately-deferred finding (MAX17048 SCL has no
  driver until the I2C host on `connectivity` is wired). See
  `power_bms_notes.md`.

- **`connectivity.kicad_sch`** -- Fanstel **BT840** (`U3`, nRF52840) plus
  `C5`/`C6`/`C7` supply decoupling. Symbol hand-authored: all 65 pins (16
  castellated, 49 LGA) from the real Fanstel datasheet Ver 1.15 Pin Function
  table. GND verified on 10/A0/B0/C0/D0/F0-F3, VDD on 9.

  The sheet notes carry what the wiring pass needs: use **SPIM3** for the
  anchor bus (the only high-speed SPI instance on the nRF52840), and avoid
  B4/B5/C3/D2 if the design might ever move to a BT840X/XE, where those are
  PA-control pins.

  Footprint still outstanding, and the datasheet contradicts itself on LGA
  count (summary says 45, its own table lists 49) -- reconcile both against
  the mechanical drawing.

- **`uwb_array.kicad_sch`** -- **four DW3210s**, `U4`-`U7`, labelled A0-A3 on the sheet. `U4` is
  the **center anchor** and does the two-way ranging; `U5`-`U7` are the outer
  anchors that timestamp the same transmission for TDoA. Symbol hand-authored
  from the real DW3000 Datasheet v1.3 Table 2.

  Kept from the module revision, because both survive the module-to-IC move
  unchanged (same DW3000 core) and both were datasheet-verified findings:
  - `R10`-`R17`, the 10k GPIO5/GPIO6 SPI-mode straps (two per anchor).
  - `R25`-`R28`, the 100k IRQ pull-downs from Qorvo Figure 11 -- a real gap
    the passives audit originally caught. Not losing it twice.

  Deleted with the modules: `C8`-`C19`. Those were sized for a single VDD3V3
  module rail and do not map onto a bare DW3210, which has VDD1 (pin 29, main
  + I/O), VDD2a/VDD2b (28/23) and VDD3 (26), **plus two decoupling-only pins**
  -- VTX_D (27) and VIO_D (38) -- that each need their own cap to ground and
  must not be tied to a rail. Decoupling is deliberately not yet placed;
  re-derive it from the IC datasheet at wiring time.

- **`regulation.kicad_sch`** -- TI `TPS62A02PDDCR` synchronous buck (`U8`,
  2.5-5.5V in / 2A, datasheet SLUSEG9E) stepping `+VSYS` down to `+3V3_SYS`.
  Chosen over the TPS563201/TPS563200 family specifically because its
  2.5-5.5V input range covers the single-cell-Li-Ion-only `+VSYS` condition
  that the 4.5V-minimum TPS563201 cannot. Includes the datasheet-recommended
  1uH inductor (`L1`), input/output caps (`C20`/`C21`), feedforward cap
  (`C22`), and feedback divider (`R8`=453k/`R9`=100k, targeting 3.318V).
  Budget re-run twice on 2026-09-19 and now ~347mA against the 2A rating
  (~5.8x) -- dropping WiFi removed the largest single load. Deliberately
  oversized and staying that way; see `regulation_notes.md`.

- **`programming_debug.kicad_sch`** *(rebuilt)* -- collapsed to what a Nordic
  part actually needs: `J3`, a 2x5 1.27mm ARM Cortex Debug SWD header, and
  `SW2`, the RESET button. Deliberately the **same debug connector as the
  wristband**, so one probe and one cable serve the whole project.

  Deleted as ESP32-specific: `R18`-`R21` (GPIO0/3/45/46 boot straps -- Nordic
  has no equivalent), `R22`+`C23` (EN reset RC -- the nRF52840 has internal
  POR), `SW1` (BOOT button -- no boot-mode pin), and `J3`+`R23`/`R24` (the
  data-capable USB-C, which existed only for ESP32-S3 native-USB flashing).

  **That last deletion resolves the two-USB-C open item** -- by removal
  rather than by choosing between connectors. The board is back to one USB-C:
  the power-only `J2` on `power_bms.kicad_sch`.

  Exact BT840 pin numbers for SWDIO/SWCLK/RESET are not filled in yet, for
  the same reason as `connectivity`.

- **`clock_dist.kicad_sch`** *(new)* -- the defining block of this board's
  architecture. Holds the shared 38.4 MHz reference network that makes TDoA
  across four receivers possible at all. Topology is TCXO -> 1:4 low-skew
  fan-out buffer -> 2200 pF AC coupling -> each DW3210's XTI, with 1 pF from
  each XTO to ground.

  Placed: `C24`-`C27` (2200 pF AC coupling) and `C28`-`C31` (1 pF XTO-to-GND)
  -- the passives whose values the DW3000 datasheet actually specifies. The
  **TCXO and buffer parts are not yet selected** (open item); the sheet
  carries the full Table 10 selection spec as an in-schematic note so
  whoever picks them has it to hand.

- **`indicators.kicad_sch`** *(new)* -- status LEDs. Before this sheet the
  bay station had no user-visible indication of any kind, which is a poor
  property for a device whose job is locating someone in trouble.
  `D4`/`R29` from MCP73871 `STAT1` (charging), `D5`/`R30` from `STAT2`
  (charge complete), `D6`/`R31` from `~PG` (external power good) -- all
  three charger outputs were previously unconnected -- plus `D7`/`R32` on an
  BT840 GPIO for firmware-driven system status. 0805 LEDs, 0603 series
  resistors at an indicative 1k.

- **`testpoints.kicad_sch`** *(new)* -- 14 probe points, chosen against this
  board's real risks rather than sprinkled evenly. `TP5` on the TCXO and
  `TP6`-`TP9` on each DW3210 XTI cover the shared clock, which is the signal
  that silently produces nonsense rather than failing loudly if it is missing
  at one anchor. `TP10`-`TP12` (SPI) plus `TP13` (A0 IRQ) and `TP14` (anchor
  reset) serve the multi-instance driver bring-up. `TP1`/`TP2` are the rails.

  **Two grounds, deliberately.** `TP3` is sited next to the clock points so a
  scope can use a short ground spring -- at 38.4 MHz a flying clip lead's
  inductance distorts what you are trying to measure. `TP4` is general
  purpose, elsewhere on the board.

  **Layout caveat on the sheet:** a test point on the clock network is a stub,
  and stubs degrade exactly the signal integrity this design depends on. Keep
  `TP5`-`TP9` minimal and on the existing routing; if layout cannot take all
  four anchor clock points, keep `TP6`/`TP7` and drop the rest -- two is
  enough to compare skew.

- **`mechanical.kicad_sch`** -- four `Mechanical:MountingHole` instances
  (`H1`-`H4`, M3 clearance, no electrical connection) at placeholder
  positions. Final positions depend on the enclosure and on the anchor
  topology, neither finalized.

### Next up

1. **Wire the sheets.** Everything is placement-only, so there are zero nets
   and the PCB has nothing to import. This is now the real blocker, ahead of
   the footprint work: power rails from `power_bms`, SPI/GPIO between U3 and
   the anchors, the clock fan-out, and the I2C bus U10/U11 share with U2.
2. **Resolve the three unassigned footprints:** U3 (BT840 -- import a vendor
   one, do not hand-author; check pad naming), L1 (pick the exact inductor
   PN) and SW2 (RESET button, no part chosen). DW3210 already has one --
   `Package_DFN_QFN:QFN-40-1EP_5x5mm_P0.4mm_EP3.6x3.6mm`, still to be
   verified against the datasheet package drawing.
3. **Draw the board outline.** Edge.Cuts is empty, which is the single open
   DRC violation. No dimensions have been decided anywhere, so this is a
   decision to make rather than a task to do.
4. Select the TCXO and 1:4 fan-out buffer, and place them on `clock_dist`.
   Add the four SMA antenna connectors to `uwb_array`.
5. Work through the open items in `../docs/decisions.md` -- cable loss,
   TCXO/buffer selection, and array calibration all gate layout. (No FCC/CE
   work: university prototype, not certified.)

## Libraries

- `libs/` -- bay-station-only symbols/footprints
- `../shared/` -- parts used on both boards (registered via
  `fp-lib-table`/`sym-lib-table`)

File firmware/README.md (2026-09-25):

# Firmware

Nothing is written yet. This tree exists so the work has a home and so the
scope is visible -- **firmware is on the critical path**, not a phase that
starts after the boards come back.

The hardware design only meets its 10-30 cm target if the software half
exists: the array calibration routine in particular is a deliverable, not a
bring-up nicety (see `../docs/positioning.md`).

## Layout

```
firmware/
  bay-station/   BT840 (nRF52840) -- drives 4x DW3210, runs the exchange, BLE to laptop
  wristband/     nRF52833 inside the DWM3001C -- the tag; transmits, and little else
  common/        shared protocol/message definitions used by both sides
  tools/         host-side: calibration, survey, analysis, test fixtures
```

## What has to get written

Roughly in dependency order.

### bay-station

1. **DW3000 driver with multi-instance support.** Qorvo's own reference stack
   targets nRF52840, so start there rather than from the ESP-IDF community
   port. **Known gap either way:** the widely used community driver
   ([br101/dw3000-decadriver-source](https://github.com/br101/dw3000-decadriver-source))
   was trimmed to one DW3000 per board and this design has four.
   Multi-instance support exists upstream and needs restoring. First task,
   and it gates everything else.
2. **Exchange scheduling.** A0 runs two-way ranging with the tag; A1-A3
   timestamp the same transmission. One tag TX, four measurements.
3. **Timestamp collection** across four chips over the shared SPI bus.
4. **Position solve** -- sphere from A0's range intersected with three
   hyperboloids from the TDoA differences. Overdetermined by one, so use the
   residual as a live quality metric. Decide on-device vs. server-side.
5. **Calibration table** -- load and apply per-anchor differential offsets.
6. **Georeferencing.** Average the MAX-M10S fix while stationary to reach
   sub-metre (host-side survey-in -- the M10 standard-precision line has no
   survey-in mode of its own). Read heading from the LIS3MDL, tilt-compensate
   it with the LIS2DH, and apply hard-iron/soft-iron calibration. Watch the
   accelerometer for the station being knocked, which invalidates both the
   fix and the heading. Note the averaging restarts at every new site.
7. **Uplink** over BLE to the laptop.

### wristband

The tag is deliberately simple: transmit, participate in the ranging
exchange with A0, sleep. It is the power-constrained side, so the whole
scheme is built around it transmitting once.

### tools

- **Array calibration.** Place the tag at surveyed positions, measure actual
  TDoA, solve for per-anchor differential offsets (antenna delay + cable
  delay together), emit the table the firmware loads. Without this the
  design does not hit its accuracy target -- Table 14 of the DW3000
  datasheet gives +/-6 cm for a *generically* calibrated node, which at a 1 m
  baseline is ~85 cm of position error.
- Analysis/plotting for bring-up measurements.

## Not yet decided

- **One** toolchain choice now, not two: both boards are Nordic (nRF52840 on
  the station, nRF52833 on the tag), so it is nRF5 SDK vs. Zephyr / nRF
  Connect SDK for the whole project. Note Qorvo publishes reference firmware
  for the DWM3001C via the DWM3001CDK, and its DW3000 reference stack targets
  nRF52840 -- start from both rather than from scratch.
- Whether the position solve runs on-device or server-side.
- Update rate and multi-tag scheduling.

Record these in `../docs/decisions.md` when they get made, same as hardware
calls.

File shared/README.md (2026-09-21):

# Shared libraries

Symbols, footprints, and 3D models used on **both** the wristband and the bay
station.

> ### Nothing in here is currently used by either board
>
> As of 2026-09-19 both boards have moved off the DWM3000, in opposite
> directions and for unrelated reasons:
>
> - **Bay station** -> discrete **DW3210**, because four modules cannot share
>   a reference clock and TDoA needs one (`../docs/positioning.md`).
> - **Wristband** -> **DWM3001C**, which folds the MCU, both antennas and an
>   accelerometer into one module (`../docs/decisions.md`).
>
> Both replacements are board-specific, so they live in the respective
> `libs/` folders. The DWM3000 symbol and footprint are **kept here
> deliberately**, not because anything uses them but because the bay
> station's discrete rework has not been built yet and this is the fallback
> if it stalls. Delete them once the DW3210 design is proven.
>
> That also means the `shared/` folder is, for now, a monorepo structure with
> nothing in it. Keep the lib-table registrations -- they cost nothing and a
> genuinely shared part may reappear -- but don't add anything here without
> checking it really is used on both boards.

- `symbols/uwb_rescue_locator_shared.kicad_sym`
- `footprints/uwb_rescue_locator_shared.pretty/`
- `3dmodels/`

Both board projects register this library in their `fp-lib-table` /
`sym-lib-table` under the nickname `uwb_rescue_locator_shared`, referenced
via `${KIPRJMOD}/../shared/...` so it resolves correctly no matter where the
repo is cloned.

If a part is only used on one board, put it in that board's own `libs/`
folder instead -- don't add it here.

## Components

| Reference/Role | Part | Symbol lib:name | Footprint lib:name | Datasheet URL | Notes/confidence |
|---|---|---|---|---|---|
| UWB transceiver module | Qorvo/Decawave DWM3000 | `uwb_rescue_locator_shared:DWM3000` | `uwb_rescue_locator_shared:DWM3000_PLACEHOLDER` | https://download.mikroe.com/documents/datasheets/DWM3000_datasheet.pdf | Pin table and package size are fully verified against the real Qorvo DWM3000 Data Sheet Rev B (May 2021), Table 2 and Figure 8. Footprint is a **PLACEHOLDER**: body size (13x23x2.9mm) and pad layout/count (24 pins: 8 left edge + 8 right edge + 8 bottom edge, none on top) are real/confirmed, but individual pad width/height are estimates, not independently measured off the datasheet's Figure 14 land-pattern drawing -- see below. |

### Part number resolved: DWM3000 (not DWM3000C, which doesn't exist)

While sourcing this part, no exact "DWM3000C" SKU turned up in Qorvo's
current catalog (checked their product pages and several distributor
listings) -- an earlier version of this doc used that name by mistake.
Qorvo's real lineup has two different, non-interchangeable parts that
could have been meant:

- **DWM3000** -- a bare UWB transceiver module (no onboard host MCU), 24-pin
  1.4mm-pitch side-castellated package, 23x13x2.9mm, based on the DW3110 IC.
  Was the choice for both boards; now used by neither.
- **DWM3001C** -- a larger module that additionally integrates an nRF52833
  BLE SoC, the antennas, and an accelerometer. **This is now the wristband's
  part**, in `../wristband/libs/`.

  **The original rejection of DWM3001C recorded here was wrong, and it is
  worth understanding why.** It read: *"Using this alongside a separate
  NINA-B111 would be redundant (two BLE radios on one board)."* That is
  true, but it evaluated DWM3001C as a replacement for the DWM3000 **while
  holding NINA-B111 fixed** -- it never considered DWM3001C replacing
  *both*. Doing so deletes a module, an antenna, a U.FL connector, a
  matching network, an entire schematic sheet and an open RF-tuning task,
  and adds an accelerometer. The comparison that was never run was the one
  that mattered.

  Worth remembering when rejecting a part in future: check you are comparing
  whole designs, not swapping one line item while everything else stays put.

All data in the `DWM3000` symbol (pin names/numbers, package dimensions)
was pulled from the real **Qorvo DWM3000 Data Sheet Rev B, May 2021**.
See `../docs/decisions.md`, where this is now marked resolved.

### The module exposes no clock pin -- and why that matters

Worth stating explicitly next to the symbol, because it drives a whole
architecture decision. The DWM3000's 24 pins are: EXTON, WAKEUP, RSTn,
GPIO7/SYNC, VDD1, 2x VDD3V3, 5x GND, GPIO8/IRQ, SPICLK, SPIMISO, SPIMOSI,
SPICSn, and GPIO0-6. **There is no XTI/XTO or other clock pin** -- the
38.4 MHz crystal is internal to the module and unreachable.

Four of these modules therefore cannot share a time base, which the bay
station's TDoA scheme requires (1 ns of clock error = 30 cm of position
error). The bare DW3000-family IC *can*: its datasheet states a 38.4 MHz
signal may be supplied from an external reference in place of a crystal, via
the XTI overdrive pin. That's why the bay station is moving discrete. Full
detail and datasheet citations in `../docs/positioning.md`.

**If you go looking for the bare IC: the DWM3000 is built on the DW3110,
which is a 52-ball WLCSP measuring 3.1 x 3.5 mm** -- chip-scale, not
hand-assemblable. The QFN40 equivalent is the **DW3210**. Don't order DW3110
by reflex just because it's the part the module datasheet names.

### Footprint verification detail

The datasheet's own Figure 14 "Module Land Pattern" gives some real,
legible numbers (overall width 13.00mm, overall land-pattern span 22.7mm,
1.00mm gap from the top edge, a 2.50mm side-pad dimension, and
2.45mm/1.40mm/1.43mm bottom-row spacing figures) but one key number doesn't
cleanly resolve: the side castellation column's stated total length
(12.925mm for 8 pads) doesn't divide out evenly against the product
brief's own stated "1.4mm pitch side castellation" spec for 8 pins. Rather
than silently pick one interpretation and present it as exact, this
footprint is named `DWM3000_PLACEHOLDER` per this project's convention
(matching how the sibling wristband-alarm project flagged its own
uncertain footprints, e.g. `PUIAudio_SMT-1341-TW-HT-R_PLACEHOLDER`) --
body outline and pad count/layout are trustworthy, individual pad
width/height are reasonable estimates only. Verify against the real
Figure 14 drawing (page 22 of the datasheet above) before fab.

### PCB layout requirement: antenna keep-out area (not yet actioned -- PCB layout hasn't started)

DWM3000 has its own onboard ceramic UWB antenna (confirmed -- no external
antenna/matching network needed for the UWB radio itself, unlike NINA-B111's
BLE antenna). The datasheet's Section 6.1 "Application Board Layout
Guidelines" (Figure 10, "Application Board Keep-Out Areas") is explicit:
ground copper should be flooded everywhere on the application board *except*
in a keep-out zone directly around the antenna, where there must be no metal
on either side, above, or below (e.g. don't place the battery under the
antenna) -- flooding metal there degrades RF performance. The keep-out
distance `d` should ideally be **10mm** from the antenna edge for the most
vertically-polarized radiation pattern; increasing `d` beyond 10mm reduces
that polarization. This applies on **both boards**, at all 5 DWM3000
placements (wristband + 4 bay-station anchors). Nothing to do about this
yet since PCB layout hasn't started on either board -- flagging it here now
so it isn't rediscovered/relearned when that phase begins.

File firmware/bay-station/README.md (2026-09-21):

# Bay station firmware

Fanstel BT840 (Nordic nRF52840). Drives 4x DW3210 over one SPI bus (four chip
selects), runs the ranging/TDoA exchange, applies the calibration table, and
reports position over BLE to a laptop.

Note **SPIM3 is the only high-speed SPI instance** on the nRF52840 (32 MHz;
the others cap at 8 MHz), so the anchor bus must use it -- and check the
silicon revision against Nordic's erratum on SPIM rates above 8 MHz.

Empty. See `../README.md` for the task list; the first job is restoring
multi-instance support in the DW3000 driver.

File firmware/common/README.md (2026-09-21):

# Shared definitions

Protocol and message definitions used by both the tag and the bay station --
frame formats, tag IDs, and whatever payload rides on the ranging exchange.

Empty. Keep this the single source of truth rather than duplicating struct
definitions on both sides.

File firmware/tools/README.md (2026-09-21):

# Host-side tools

Not firmware -- things that run on a laptop.

- **Array calibration**: the important one. Emits the per-anchor delay table
  the bay-station firmware loads. The design does not meet its accuracy
  target without it.

  Two distinct jobs, and they have different requirements -- see
  `../../docs/positioning.md`:
  - A0's *absolute* antenna+cable delay, which sets the range scale. Maps
    1:1 into radial error, so ~10 cm of equivalent path accuracy is enough
    for a 10 cm target -- but it does need a known true distance.
  - A1-A3's delay *relative to A0*, which sets bearing. Amplified by
    `range/B` (10x at 10 m on a 1 m baseline), so needs to be ~10x tighter,
    around 1 cm. Does NOT need a known distance -- only the same signal
    observed simultaneously, so tag-position error largely cancels.
- Bring-up analysis and plotting.

Empty.

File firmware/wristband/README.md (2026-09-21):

# Wristband firmware

Nordic nRF52833, inside the DWM3001C. The tag: participates in the two-way ranging
exchange with the bay station's center anchor, then sleeps.

Deliberately minimal -- the wristband is the power-constrained side, which is
why the positioning scheme is built around one transmission per fix.

Empty. See `../README.md`.

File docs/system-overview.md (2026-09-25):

# System overview

## Concept

A worn **wristband** tag is located in 3D space by a fixed **bay station**
with four UWB anchors. The bay station reports position **over Bluetooth LE
to a nearby laptop**, and georeferences itself with GNSS plus a magnetometer
so those positions can be given as world coordinates. Intended use: an
outdoor safety/rescue tracking system.

Note this is narrower than the original concept, which had the station
uploading to the internet. That was dropped deliberately on 2026-09-19 once
the team confirmed a laptop will always be present -- and it is what allowed
the host MCU to move to Nordic. See `decisions.md`.

Positioning is a **hybrid of two-way ranging and TDoA**: a center anchor
ranges to the tag for distance, and three outer anchors measure arrival-time
differences against that center anchor for direction. Target is **10-30 cm
at ~10 m on Channel 5 (6489.6 MHz)**. The full scheme, its error budget, and
the clock architecture it forces are in [`positioning.md`](positioning.md) --
read that one first if you're touching anchors, clocking, coax, or
connectors.

```
                         A1 ← antenna on coax
                            \
   ┌─────────────┐           \      ┌───────────────────────────┐
   │  Wristband   │  UWB       ○────│  Bay Station (ONE PCB)     │
   │  (worn tag)  │ ═════════▶ A0   │  4x DW3210, one TCXO       │
   └─────────────┘  one TX    / \   │  BT840 (nRF52840) host     │
                             /   \  └───────────┬────────────────┘
                           A2     A3            │ Bluetooth LE
                      antennas on ~1-2 m        ▼
                      coax, rigid frame       Laptop

   A0     two-way ranging  -> range to tag
   A1-A3  TDoA vs. A0      -> direction to tag

   All four transceivers share one clock on the board.
   Only the antennas are remote.
```

## Boards

| | Wristband | Bay Station |
|---|---|---|
| Role | Worn tag | Fixed reference station |
| UWB | 1x DWM3001C module (UWB + MCU + antennas in one part) | 4x DW3210 IC, all on one PCB; 1 center + 3 outer roles, antennas remote on coax |
| MCU/radio | Nordic nRF52833, inside the DWM3001C (resolved) | Nordic nRF52840, in a Fanstel BT840 module (resolved) |
| Power | Single-cell battery + BMS, sized for just enough runtime -- core function takes priority over battery life | Battery + BMS optimized for longevity, not size |
| Link to the outside | None (talks only to the bay station over UWB) | BLE to a nearby laptop. No internet uplink -- see note above |
| Georeferencing | n/a | MAX-M10S GNSS + LIS3MDL magnetometer + LIS2DH accelerometer. Position AND heading are both needed to place a frame-relative bearing on a map |

## UWB part status

**The bay station's schematic is out of date.** It currently shows four
**DWM3000** modules; the resolved design is four discrete **DW3210** ICs
(QFN40) on the one PCB sharing a single 38.4 MHz TCXO, with the antennas
remote on coax. The module exposes no clock pin, so four of them cannot share
a time base, and TDoA needs one. See `decisions.md` and `positioning.md` for
the datasheet evidence and the full cost of the change.

The wristband is unaffected -- a single transceiver has nothing to
synchronize against, so the DWM3000 module stays the right fit there.

## Interface between the boards

There is **no physical connector** between the wristband and the bay
station -- the only link is the UWB radio. Still to be specified:

- **Channel 5 (6489.6 MHz)** -- resolved, see `decisions.md`
- PRF, preamble, and data rate
- Ranging exchange format and update rate
- Tag ID / payload format riding on the ranging frames
- Multi-tag support: how many, and how they're scheduled

## Bay station internal interfaces

All on-board, and part of the bay station's own design:

- **4x DW3210 -> BT840**: one shared SPI bus (MOSI/MISO/SCLK) with four chip
  selects, plus per-chip IRQ. DW3000 runs to 36 MHz; note **SPIM3 is the only
  high-speed SPI instance on the nRF52840** (32 MHz; the others cap at 8 MHz),
  so the anchor bus must use it -- and check the silicon revision against
  Nordic's erratum on SPIM rates above 8 MHz.
- **Clock**: one 38.4 MHz TCXO -> 1:4 low-skew fan-out buffer -> each chip's
  XTI via 2200 pF AC coupling, with 1 pF from each XTO to ground.
- **Antennas**: four SMA coax runs, ~1-2 m, to a rigid frame. CH5 is above
  U.FL's 6 GHz rating, so SMA is required. Cable loss at 6.5 GHz is the last
  unverified number, though it does not gate baseline length -- the size of
  the rigid antenna frame does. See `positioning.md`.

## Bay station -> laptop

Bluetooth LE from the BT840. Nordic parts are BLE-only -- no Bluetooth
Classic, so no SPP -- which means a GATT service rather than a virtual COM
port. USB-CDC over a cable is the simpler alternative and worth considering,
since the station is wired for power anyway.

Still open: the protocol itself, and whether the station sends raw timestamps
for a host-side solve or a position it computed itself.

## Open decisions

See [`decisions.md`](decisions.md).

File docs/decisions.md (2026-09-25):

# Decision log

Open calls first, resolved calls below with the reasoning, so we don't
relitigate them. Keep this updated as the team decides things.

## Open

- **U8 `lib_symbol_issues` warning -- investigated, deliberately NOT "fixed".**
  ERC reports `Symbol 'TPS62A02PDDCR' not found in symbol library
  'Regulator_Switching'`. The library's actual symbol is `TPS62A02PDDC`,
  without the trailing R (that is TI's tape-and-reel suffix on the orderable
  part number, not part of the symbol name).

  **Do not simply rename it.** KiCad's `TPS62A02PDDC` is defined as
  `(extends "TPS62A01PDDC")`, and this repo has been bitten by `extends`
  before: `kicad-cli` fails to load an entire file, silently, reporting zero
  components and zero violations. Pointing U8 at a lib_id that does not
  resolve means the flattened 6-pin copy embedded in `regulation.kicad_sch`
  is always used -- which may well be why it was done this way, matching the
  flattened-copy workaround already used for AO3401A and MCP1700.

  So the warning is arguably the correct trade rather than a defect. Decide
  deliberately: either keep it and annotate the sheet, or rename to
  `TPS62A02PDDC` and re-verify that ERC still reports a non-zero component
  count. Do not change it without that check.

  Separately, three parts on the schematic have **no row in
  `libs/components.csv`** at all, found 2026-09-23 while cross-checking the
  board against a `kicad-cli sch export bom` run:

  - **U8**, the buck converter itself -- only its inductor L1 has a row.
  - **SW2** (RESET button) and **J3** (SWD header), both added when
    `programming_debug.kicad_sch` was rebuilt for Nordic. The BOM was never
    updated to match.

  **SW2 additionally has no footprint assigned**, which puts it in the same
  bucket as L1 and U3 (BT840) -- the three parts that cannot be placed on the
  PCB today. L1 and U3 are recorded as known gaps; SW2 was not. None of the
  three has a chosen part number yet, so no rows are being invented here.

### Environment and georeferencing -- what the enclosure does not cover

The bay station gets an **enclosure** (resolved 2026-09-23), which settles
ingress rating and weatherproofing the SMA/coax and GNSS antenna entries.
Those are enclosure-design problems now, not board problems. What a box does
not settle:

- **The enclosure has to pass RF.** The BT840's BLE link to the laptop runs
  off an antenna printed on the module itself, which is inside the box. A
  metal enclosure would kill that link. Either the enclosure is
  plastic/RF-transparent, or the BLE antenna moves outside -- and no RF
  connector is placed for that, so the first option is the assumption until
  someone says otherwise. Only BLE is exposed to this: the four UWB antennas
  are already remote on coax and the GNSS antenna is external on SMA.
- **Li-Ion charging below 0 degC.** An enclosure keeps water out, not cold
  out; an unheated box tracks ambient. Most single-cell Li-Ion must not be
  charged below freezing -- doing so plates lithium and permanently damages
  the cell. The MCP73871 has a THERM input and an NTC is placed, but
  `power_bms_notes.md` records it only as "10k per the datasheet's typical
  application circuit" -- it has never been sized for a specific cold-charge
  cutoff.
- **Temperature range across the BOM.** Same reason: the interior tracks
  ambient plus self-heating. Nothing has been checked against a range;
  several parts are specified at Tamb = 25 degC in the notes.
- **GNSS survey-in warm-up.** Not environmental at all. Absolute coordinates
  are not trustworthy until the average settles, and that restarts at every
  site. Relative UWB positioning is available immediately. Decide what the
  operator sees during warm-up so a coarse early fix is not mistaken for a
  settled one.
- **Magnetometer calibration procedure.** Hard-iron/soft-iron calibration is
  needed per build, and the enclosure is now part of what gets calibrated
  out -- ferrous fasteners or a steel lid sit fixed relative to U10. Calibrate
  with the board in its enclosure, not on the bench. No procedure exists.

### Firmware

- **No GPIO on either MCU is assigned to a function.** Recorded 2026-09-25
  from `kicad-cli sch export netlist --format kicadsexpr` on both boards:
  bay station reports 341 nets of which only 19 are named, all of them from
  `power_bms`/`regulation`; every one of the BT840's 65 pins and all 40 pins
  on each of U4-U7 (DW3210) sit on `unconnected-(...)` nets. The wristband on
  `dwm3001c-migration` is further along but still thin -- 12 of the
  DWM3001C's 48 pins are tied (power, GND, SWD, `RESET_N`, `VBAT_SENSE`, and
  `P0.17` to the SOS button).

  This is the gate on firmware, not the toolchain question below. Firmware
  task #1 on the station is a multi-instance DW3000 driver, and it cannot be
  written without knowing which SPI instance and which four CS and four IRQ
  lines it owns. The specific decisions needed:

  - SPI instance for the shared DW3210 bus, and whether it can clock at the
    DW3000's rated maximum on the chosen pins.
  - Four CS lines, four IRQ lines, and the shared RSTn.
  - Whether A0 gets any distinct signal, given it is not a peer of A1-A3.
  - Wristband: the DWM3001C's internal nRF52833-to-DW3110 wiring is fixed by
    the module, so the open part is only what the remaining external pins do.

  Until these land, firmware should write against named constants in
  `firmware/common/` rather than pin numbers. See `firmware/CLAUDE.md`.

  Minor, but it will end up in code: the wristband net is spelled
  **`SOS_BNT`** (`/Radio MCU/SOS_BNT`). Almost certainly meant to be
  `SOS_BTN`; worth fixing before firmware names a symbol after it.

- **Toolchain: nRF5 SDK vs. Zephyr / nRF Connect SDK.** One choice for both
  boards, since both are Nordic. Already flagged in `firmware/README.md`;
  recorded here so it is tracked with every other open call. Note this also
  decides the *form* of the generated pin map -- a devicetree overlay under
  Zephyr, a plain C header under nRF5 SDK -- so it should be settled before
  anyone builds that generator.

### Critical path for the bay station

- **Baseline length: 1 m as specified, but bigger is nearly free.** Corrected
  2026-09-19: cable loss was previously recorded as the constraint on
  baseline. It is not. With ~17 dB of link margin and ~1 dB/m for decent coax
  at CH5, even 5 m spends under a third of the budget. **The real cap is the
  size of rigid frame the team is willing to build.** This matters because at
  1 m the 10 cm target depends on averaging, while at 3 m it falls out of a
  single shot -- the cheapest accuracy in the design, costing no parts and no
  firmware. Decide the frame size deliberately rather than defaulting.
- **Cable loss per metre at 6.5 GHz for the chosen coax** -- still worth
  verifying (every figure quoted so far is an estimate), but it is no longer
  a gating number. It sets how much of the 17 dB you spend, which feeds
  timestamp precision via SNR.
- **Import vendor footprints for BT840 and DWM3001C.** Neither should be
  hand-authored: both land patterns exist only as mechanical drawings, and
  guessing pad geometry on a 65- or 48-pad module is not a risk worth taking.
  Sources found: SnapMagic/SnapEDA lists a **Qorvo-provided** DWM3001C
  symbol/footprint/3D model, and both SnapMagic and Ultra Librarian list
  BT840 -- plus Fanstel ships a 61-pin library component with its EV-BT840F
  V4 Gerbers. Note that 61-pin part omits F0-F3, which are real solderable
  ground pads; see the pin-count item below before trusting it.

  **When importing, check pad naming.** KiCad matches symbol pins to footprint
  pads *by name*. Both symbols here use the datasheets' own schemes -- BT840
  as 1-16 then Z0-Z6/A0-A6/B0-B6/C0-C6/D0-D6/E0-E6/F0-F6, DWM3001C as 1-48.
  A vendor footprint numbered differently will silently connect nothing.
  Also confirm what the vendor does with DWM3001C pin 18, which its own
  datasheet leaves undocumented.
- ~~Reconcile the BT840 pin count~~ -- **resolved at 65, after a wrong turn.**
  The datasheet summary says 45 LGA while its own Pin Function table lists
  49 designators. An intermediate revision of this symbol dropped F0-F3 to
  reach 61, reasoning that they are bare "Ground pad" entries with no ball
  reference and that 16+45=61 matched Fanstel's library component. **That was
  wrong.** A real BT840 footprint shows F0-F3 as 1.4986mm SQUARE pads, far
  larger than the 0.6mm circular signal pads -- physical pads that must be
  soldered and grounded. The stated 45 evidently counts only signal pads.
  Symbol models all 65. Three agreeing numbers were agreeing with each other,
  not with the part.
- **TCXO + 1:4 low-skew fan-out buffer part selection**, against the DW3000
  Table 10 external-reference spec (0.8 V to VDD2 Vpp, AC coupled via 2200
  pF, -132 dBc/Hz @ 1 kHz, -145 dBc/Hz @ 10 kHz, 40-60% duty). See
  `positioning.md`.
- **Array calibration procedure and fixture.** Not optional -- the design
  does not close without it. Table 14's +/-6 cm generic-calibration residual
  would give ~85 cm of position error at a 1 m baseline, three times worse
  than the loosest target. Measured once at manufacture, since the rigid
  frame fixes both geometry and cable lengths.

  **Note the two halves are not the same job** (full treatment in
  `positioning.md`):
  - **A0** needs its *absolute* antenna+cable delay. Error maps 1:1 into
    radial range error. Needs a known true distance to measure against.
  - **A1-A3** need their delay *relative to A0*. Error is amplified by
    `range/B` -- 10x at 10 m on a 1 m baseline -- so these must be ~10x
    tighter than A0's (~1 cm equivalent path, vs ~10 cm for A0). They do
    *not* need a known distance, only the same signal observed
    simultaneously, so tag-position error largely cancels.

  The harder target is also the one needing less reference equipment. Design
  the fixture around that.
- **Captive vs. detachable antenna assembly.** A user-swappable cable
  invalidates the delay calibration. Leaning captive; confirm against
  serviceability requirements. (This used to be partly a regulatory question
  too -- see the certification entry under Resolved, which removes that half
  of it.)
- **Multi-instance driver support.** This design drives four DW3210s from one
  host; the common community driver (`br101/dw3000-decadriver-source`) was
  trimmed to one DW3000 per board. Multi-instance support exists in Qorvo's
  upstream driver and needs restoring. **Easier since the move to Nordic** --
  Qorvo's reference stack targets nRF52840 directly, so this is now working
  with the vendor grain. Still scope it before it surprises anyone.
- **Is SYNC/OSTR needed at all** now that the clock is genuinely shared? The
  DW3000 **User Manual** (not the datasheet) documents the one-shot timebase
  reset procedure. Read it before committing the schematic.
- **Mechanical frame design**: the rigid structure carrying the four
  antennas, including the A0 out-of-plane offset (see `positioning.md`).
- **Firmware**: nothing written, nothing assigned, and it is on the critical
  path -- the accuracy target is not met without the array calibration
  routine. Both boards are now Nordic (nRF52840 on the station, nRF52833 on
  the tag), so the remaining framework choice is a single one -- nRF5 SDK vs
  Zephyr / nRF Connect SDK -- rather than one per board. Where the position
  solve runs is also open. Skeleton and task list in `../firmware/README.md`.
- **LED drive rails and GPIO allocation.** The status LEDs are placed
  (`indicators.kicad_sch` on both boards) with indicative 1k series
  resistors. Confirm the drive rail for each and recompute, and allocate the
  GPIOs on each board's Nordic part for the two system-status LEDs.

### Everything else

- **Bay station uplink backend**: what protocol/service position data gets
  sent to, and whether the station sends raw timestamps for a server-side
  solve or computes the position itself.
- **UWB link parameters**: PRF, preamble, data rate, update rate, and
  multi-tag scheduling. (Channel is resolved -- CH5, see below.)
- **Antenna part selection.** Candidates covering CH5, existence and band
  confirmed from vendor product pages but full datasheets not yet pulled:
  Taoglas UWC.01 (6-8 GHz SMD chip), ILA.68 (LTCC 6-8.5 GHz), UWCCP.01
  (circularly polarized). Abracon ACR1004U is 3-6 GHz and does **not** cover
  CH5. Verify before BOM.
- **PCB layer count / stackup for the WRISTBAND** -- still a layout-phase
  call, likely 4-layer for RF. The bay station's is resolved and is now in
  the board file; see Resolved below.
- **Wristband module keep-out and edge spacing** -- two real DWM3001C
  datasheet requirements, neither actionable until layout starts:
  - **Section 7.1**: minimum 10mm with no metal either side of the module
    antenna, nothing above, below or beside it. Do not place the battery
    under the antenna. Ground flooded everywhere else.
  - **Section 7.2**: keep the module at least 1cm from the PCB edge. The
    antenna is cross-polarized in some regions, which helps link budget as a
    worn tag changes orientation, but that diversity can make ranging
    accuracy vary in harsh multipath. Qorvo's stated mitigation is the 1cm
    edge spacing, which reduces the horizontally polarized component.

  Moot for the bay station, which uses discrete ICs with remote antennas.
- **Bay station L1 (buck converter inductor) footprint**: the chosen part
  (Coilcraft XGL3520-102MEC) has no matching footprint in KiCad's default
  libraries -- pick/verify a real footprint at BOM time (see
  `bay-station/regulation_notes.md`).
- **Bay station power budget: re-check when the clock parts land.** Re-run
  twice on 2026-09-19 and now ~347mA against the TPS62A02's 2A (~5.8x). Three
  lines are estimates rather than datasheet figures -- the TCXO (~2mA), the
  1:4 fan-out buffer (~25mA), and the BT840 host (~20mA, since the Fanstel
  datasheet has no current table). Confirm both
  once chosen, along with whether the MCP73871 status LEDs pull from
  `+3V3_SYS` or `+VSYS`.

## Resolved

- **Bay-station stackup: 4 layers, 1.048 mm, controlled impedance.** Resolved
  2026-09-23 and now actually present in `bay-station.kicad_pcb`, which until
  this point was an empty 2-layer default stub contradicting the decision
  recorded here.

  Taken from DW3000 Datasheet v1.3, Section 7.3.2 Figure 35 "Recommended QFN
  Stack-up". The QFN variant is the one that applies -- this board uses the
  DW3210 (QFN40), not the WLCSP DW3110 that Figure 34 covers:

      F.Cu     35 um
      prepreg 254 um
      In1.Cu   35 um
      core    400 um
      In2.Cu   35 um
      prepreg 254 um
      B.Cu     35 um     = 1.048 mm finished

  Section 7.3's remaining requirements are recorded as a text note on the
  board's `Cmts.User` layer rather than repeated here, because they are
  layout instructions and that is where whoever does layout will see them:
  50 ohm impedance-controlled RF1/RF2 with the 2 pF DC-block pads embedded
  in the track at full width; ground copper removed under each DW3210 on
  F.Cu and In1.Cu, with In2.Cu as the first solid plane; analog, power and
  digital groups kept apart. If the stackup is ever changed, that first solid
  plane must stay at least 0.25 mm below F.Cu.

  **The dielectric constants are NOT from the datasheet**, which gives
  thicknesses only. KiCad's FR4 defaults (er 4.5, tan d 0.02) sit in the file
  as placeholders. Controlled impedance means the fab's stackup governs, and
  1.048 mm is not a catalogue thickness -- expect to take their numbers and
  re-solve trace widths rather than trusting anything geometric in the file.

- **Default netclass clearance cut from 0.2 mm to 0.15 mm.** Resolved
  2026-09-23. The DW3210 cannot physically satisfy 0.2 mm: KiCad's
  `QFN-40-1EP_5x5mm_P0.4mm_EP3.6x3.6mm` has 0.25 mm pads on a 0.4 mm pitch,
  leaving exactly 0.15 mm between neighbours. At 0.2 mm every adjacent pad
  pair on all four anchors would have failed DRC the moment footprints were
  placed. 0.15 mm leaves zero margin on that one geometry -- which is the
  part dictating the number -- and is comfortably inside standard fab
  capability everywhere else on the board.

- **The bay station gets an enclosure.** Resolved 2026-09-23. This closes the
  items that opened when outdoor deployment was confirmed: ingress rating,
  weatherproofing the four UWB SMA entries and the GNSS antenna entry, and
  weather exposure of the rigid antenna frame. All of it is enclosure design
  rather than board design, and it is not tracked here any further.

  Not selected or costed yet, and it does not cover what a box cannot: cold
  charging, BOM temperature range, and RF transparency for the BT840's
  on-module BLE antenna. Those three stay Open above.

- **GNSS + orientation added to the bay station** (`gnss.kicad_sch`, new
  sheet). Resolved 2026-09-23. The station is deployed outdoors and moved
  between sites, and the array only ever produced position RELATIVE to its
  own frame -- fine for an operator standing at it, useless as a coordinate
  to hand anyone else.

  **Position alone was not enough, and this is the part that is easy to
  miss.** A GNSS fix says where the station is, not which way it faces. The
  array reports a bearing relative to the frame, so without heading you get a
  circle of possible tag locations rather than a point. Hence three parts,
  not one:
  - **U9 u-blox MAX-M10S** -- where the station is.
  - **U10 ST LIS3MDL** magnetometer -- which way it faces.
  - **U11 ST LIS2DH** accelerometer -- tilt compensation, because a
    magnetometer only reads heading correctly when level and this station is
    set down on varying terrain. It also detects the station being knocked,
    which silently invalidates both the fix and the heading.

  **All three are KiCad stock symbols AND footprints** -- deliberate. The
  board already carries two outstanding vendor-footprint imports; a third was
  not worth it. u-blox SAM-M10Q with its integrated patch antenna was the
  alternative and would have deleted the GNSS antenna entirely, but KiCad has
  neither symbol nor footprint for it. MAX-M10S needs an external antenna at
  1.575 GHz, which is far easier routing than the 6.5 GHz UWB work already on
  this board.

  **Accuracy, recorded so it is not a surprise.** Uncorrected GNSS is 2-5 m
  against the array's 10-30 cm -- the world-frame anchor is 10-30x coarser
  than the relative fix hanging off it. Team chose **survey-in**: firmware
  averages the station's own fix while stationary to reach sub-metre.
  Operational cost, given the station moves between deployments: that
  averaging restarts at every site, so absolute coordinates have a warm-up
  that relative UWB positioning does not. Averaging is host-side on the
  BT840 -- u-blox's own "Survey-In" is a timing/RTK-part feature, not M10
  standard-precision, and host averaging is equivalent for static
  self-positioning without a pricier module.

  Pin data verified against u-blox Data Sheet UBX-20035208 R02 Table 9:
  KiCad's symbol matches 17 of 18 pins. **Pin 15 differs** -- "Reserved" in
  R02, `VIO_SEL` in KiCad, probably a later revision. Leave it open and check
  the current datasheet. Datasheet also requires VCC (8) and V_IO (7) tied
  together, and SAFEBOOT_N (18) left open.

- **No power switch on the wristband.** Confirmed 2026-09-19. The tag is live
  from the moment a cell is connected, and the only thing that ever cuts the
  rail is the DW01A protection IC at overdischarge. Recorded because the
  absence of a switch previously looked like an oversight rather than a
  choice, and because it has two consequences worth knowing: shelf life is
  bounded by self-discharge plus quiescent draw rather than by being switched
  off, and the only way to check rail state without disconnecting the cell is
  TP1/TP2 on `testpoints.kicad_sch`.

- **Test points added to both boards** (`testpoints.kicad_sch`, new sheet on
  each). Zero existed before, on a design whose central difficulty is
  sub-nanosecond timing and per-anchor delay calibration -- bring-up would
  have meant measuring a board with nowhere to attach a probe. Free now,
  impossible after layout.

  Bay station, 14 points chosen against this design's actual risks: the
  shared clock (TP5 at the TCXO, TP6-TP9 at each DW3210 XTI -- if the
  reference is missing at one anchor, TDoA produces nonsense rather than
  failing loudly), the SPI bus and anchor IRQ/reset for the multi-instance
  driver work, both power rails, and **two** grounds. TP3 is deliberately
  sited next to the clock points so a scope can use a short ground spring:
  at 38.4MHz a flying clip lead's inductance distorts the measurement.

  Wristband, 5: both rails, two grounds, and a firmware timing marker on a
  spare GPIO so tag-side exchange timing is visible on a scope.

  **Layout caveat recorded on the sheet:** a test point on the clock network
  is a stub, and stubs degrade the very signal integrity this design depends
  on. Keep TP5-TP9 as minimal pads on the existing routing; if layout cannot
  take all four anchor clock points, keep TP6/TP7 and drop TP8/TP9 -- two is
  enough to compare skew.

- **DW3210 footprint: KiCad stock `QFN-40-1EP_5x5mm_P0.4mm_EP3.6x3.6mm`.**
  Verified to exist in KiCad 8.0.6 and checked geometrically -- 40 signal
  pads, pad 1 at y = -1.8mm with 0.4mm pitch spanning 3.6mm, correct for 10
  pins per side on a 5x5mm body. It is also the only QFN-40 5x5mm 0.4mm-pitch
  variant KiCad ships; the EP3.5 and EP3.7 variants do not exist.

  **One caveat carried deliberately:** the exposed-pad size is unverified.
  The DW3000 package drawing is Figure 38, an image, so D2/E2 do not extract
  as text. KiCad's 3.6 x 3.6mm EP comes from a generic Microchip packaging
  spec, and other vendors' 40-lead 5x5 QFNs use 3.7 x 3.7mm. A slightly
  smaller pad than the part's own EP is the conservative direction -- less
  copper, no bridging risk, some thermal loss -- which is the same call
  already made and documented for the MCP73871. Check Figure 38 before fab.

- **Superseded parts are removed from schematics, not left in place.**
  Convention set 2026-09-19 after the bay station ended up with three sheets
  holding silicon that two architecture decisions had already replaced
  (ESP32-S3 on `connectivity`, 4x DWM3000 on `uwb_array`, ESP32-specific
  programming circuitry on `programming_debug`).

  The problem with leaving them: **a schematic containing the wrong part
  emits a wrong BOM and a wrong ERC.** `libs/components.csv` said DW3210 and
  BT840 while the schematic said DWM3000 and ESP32-S3 -- two checked-in files
  confidently disagreeing about the two most expensive parts on the board.
  A "pending rework" label in a README does not reach anyone generating a
  BOM from KiCad.

  **The rule: when a part is superseded, delete it from the sheet and leave a
  specification note in its place** -- what the replacement is, why, and what
  the person placing it needs to know. An empty sheet carrying a correct spec
  is strictly better than a populated sheet carrying a wrong one. Keep any
  passives whose requirement genuinely survives the change, and say which
  ones and why.

  Applied: `uwb_array` kept R10-R17 (GPIO5/6 straps) and R25-R28 (Figure 11
  IRQ pulldowns) because both are DW3000-core requirements unchanged by the
  module-to-IC move, and dropped C8-C19 because module decoupling does not
  map onto a bare IC with separate VDD1/VDD2/VDD3 rails. `connectivity` kept
  its generic 3V3 decoupling. `programming_debug` was rebuilt outright.

- **Bay station uplink: BLE to a laptop, not WiFi to the internet.** Resolved
  2026-09-19. The station now talks Bluetooth LE to a nearby computer. Note
  this is a real scope change from the original concept, which had the bay
  station uploading position data to the internet -- that is no longer what
  it does, and `system-overview.md` has been corrected accordingly.

  Confirmed with the team that a laptop will always be present, which is what
  made the MCU change below possible. **If that ever stops being true, both
  decisions reopen together.**

  Two consequences worth knowing: BLE range reaches a nearby laptop, not a
  router, and Nordic parts are BLE-only with no Classic/SPP -- so the link is
  a GATT service (or USB-CDC over a cable, which is simpler still and worth
  considering since the station is wired for power anyway).
- **Bay station MCU: Fanstel BT840 (Nordic nRF52840)**, replacing
  ESP32-S3-WROOM-1. Resolved 2026-09-19, and only possible because of the
  decision below it: the uplink moved from WiFi to BLE-to-a-laptop, and the
  team confirmed the station will never need to reach the internet without a
  laptop present. WiFi was the single reason Nordic was excluded.

  What it buys:
  - **One toolchain for the whole project.** The wristband already runs an
    nRF52833 inside its DWM3001C. Both boards become Nordic -- one SDK, one
    debug workflow -- instead of Nordic on one and ESP-IDF on the other.
    This matters because firmware is unstaffed and on the critical path.
  - **It attacks the hardest open firmware item head-on.** "Restore
    multi-instance DW3000 driver support" is critical path precisely because
    the community ESP-IDF port was trimmed to one chip per board. Qorvo's own
    reference stack targets Nordic (the QM33120WDK1 ships on nRF52840 DKs),
    so this works with the vendor grain rather than against it.
  - **`programming_debug.kicad_sch` collapses.** Nordic programs over SWD,
    which deletes the ESP32-S3 boot-strap resistors on GPIO0/3/45/46, the EN
    RC delay, and the native-USB flashing path -- see the two-USB-C item,
    now resolved by deletion.

  Costs, accepted: about +$3.40 per board ($6.88 vs ~$3.50); WiFi is gone
  structurally rather than provisionally; and `connectivity.kicad_sch` plus
  `programming_debug.kicad_sch` both need rebuilding.

  **Package note.** BT840 is 14 x 16 x 1.9mm with *hybrid* pins -- 16
  castellated plus 45 LGA. The datasheet notes SMT equipment is not needed
  for the castellated pins alone, but this design needs roughly 17-20 signals
  (3 SPI + 4 CS + 4 IRQ + reset + 2 SWD + 2 I2C + LED + power), so **the LGA
  pads are required** and the part must be reflowed. That is not a new
  constraint: the DW3210 is a QFN40 at 0.4mm pitch, so this board already
  needed reflow.

  **Symbol authored 2026-09-19** -- all 61 pins from the real Fanstel Pin
  Function table, once it was extracted with `pdftotext -raw`. An earlier
  pass wrongly concluded this was blocked: it had only tried `-layout`, which
  interleaves the BT840 and BT832 columns. The lesson is now a hard rule in
  `CLAUDE.md` -- a scrambled table means the wrong extraction mode, not
  missing data. Footprint should be imported from a vendor library rather
  than hand-authored; see Open.

- **Positioning scheme**: hybrid **two-way ranging + TDoA**. One center
  anchor does two-way ranging with the wristband for absolute range; three
  outer anchors timestamp the same tag transmission and yield TDoA against
  the center anchor for direction. Chosen over pure TWR-from-four-anchors
  (four bidirectional exchanges would cost tag air time and battery, and the
  wristband is the power-constrained side) and over pure TDoA (no absolute
  scale from a single burst). One tag transmission yields four measurements.
  Full writeup, math, and error budget: `positioning.md`.
- **No regulatory certification.** This is a **university prototype** -- not
  marketed, not sold, not deployed as a product -- so it does not go through
  FCC/CE intentional-radiator testing. Confirmed 2026-09-19.

  This matters more than it sounds: losing the DWM3000 module's pre-certified
  status was previously the single largest cost of moving to discrete
  DW3210s, and it is now simply not a cost. The discrete decision gets
  materially cheaper and lower-risk as a result.

  **If this ever becomes a product, certification comes straight back**, and
  it is not a small retrofit -- an intentional radiator has to be tested as
  the assembly it ships as, including the antenna and cable. Anyone reviving
  this for production should treat certification as a first-class schedule
  item, not a finishing step. Two design choices made here point that way
  anyway (a BPF on RF1/RF2 per the datasheet's note about regions mandating
  conducted testing, and a captive antenna assembly), so the door is left
  open rather than closed.
- **Performance target**: **10-30 cm accuracy at ~10 m range.** Set
  2026-09-19. This had been missing from the repo entirely; everything in
  `positioning.md` is derived from it, so changing it changes the design.
- **Status indication added to both boards.** Until 2026-09-19 the system had
  **zero LEDs** -- no way to tell whether either board was powered, charging,
  charged, or working -- while MCP73831's `STAT` and MCP73871's
  `STAT1`/`STAT2`/`~PG` all sat unconnected. Poor for a device whose purpose
  is locating someone in trouble, and much cheaper to fix at schematic stage
  than after layout. New `indicators.kicad_sch` on each board: wristband
  `D2`/`D3` (0603), bay station `D4`-`D7` (0805), each with a 0603 series
  resistor. Both boards also get one MCU-driven system-status LED so firmware
  can signal ranging/fault. Resistor values and drive rails are indicative --
  tracked under Open.
- **New sheets for the reworked architecture.** `uwb_anchors.kicad_sch`
  renamed to `uwb_array.kicad_sch` (the four receivers are one on-board
  array, not distributed anchor units), and `clock_dist.kicad_sch` added to
  hold the shared-reference network that defines this architecture. Both
  boards gained `indicators.kicad_sch`. Bay station is now 8 sheets,
  wristband 8.
- **UWB channel: Channel 5 (6489.6 MHz)**, not Channel 9. Chosen because the
  architecture is coax-fed: cable loss and free-space path loss both scale
  with frequency, so CH5 directly buys baseline length and range. Also sets
  antenna selection and connector rating. Revisit only if regulatory rules in
  a target market forbid it.
- **Anchor topology: all four transceivers on the one bay-station PCB
  sharing a single clock, with the four antennas remote on ~1-2 m coax.**
  Chosen 2026-09-19 over three alternatives:
  - *Four DWM3000 modules on one PCB* -- impossible. No clock pin, and a
    board-sized ~0.1 m baseline gives ~17 degrees of bearing error.
  - *Four discrete anchors on satellite boards, clock over the harness* --
    works, but pushes the timing problem into cables and multiplies BOM.
  - *Wireless clock-calibration-packet sync between independent anchors* --
    works, keeps the modules and their certification, but moves the entire
    problem into firmware.

  Putting all four receivers on one board makes synchronization
  **structurally absent rather than solved**: one oscillator, short matched
  traces, no drift model, no sync firmware. The cost moves into the RF path,
  where it becomes a link-budget question instead of a timing one. Accepted
  because CH5 leaves ~17 dB of link margin at 10 m, comfortably covering the
  2-5 dB of expected cable loss.
- **UWB: module vs. discrete IC** -- the bay station moves from the DWM3000
  module to the **bare DW3000-family IC** so all four anchors can share one
  38.4 MHz reference. TDoA compares timestamps across receivers, and 1 ns of
  clock error is 30 cm of position error. The DWM3000 module makes that
  impossible: its 24 pins (verified symbol in `shared/symbols/`) include no
  clock pin, and its crystal is internal and unreachable. The bare IC does
  support it -- DW3000 Datasheet v1.3 Table 10: "A 38.4 MHz signal can be
  provided from an external reference in place of a crystal if desired", with
  XTI documented as the "external reference overdrive pin" and XTO needing
  "1pF to the ground, only if external clock is used." **The wristband keeps
  the DWM3000 module** -- a single transceiver has nothing to synchronize
  against, so none of this applies.
- **Clock implementation: one TCXO + a 1:4 low-skew fan-out buffer**, not a
  shared passive crystal. A crystal cannot be shared -- each chip's XTI/XTO
  pair forms its own oscillator, so four chips would be four oscillators,
  which is the problem rather than the fix. Buffer output skew is a fixed
  per-chip offset and calibrates out with cable delay; only skew *stability*
  matters, which on-board is negligible. Selection spec in `positioning.md`.
- **Mechanical: rigid antenna frame, not field-installed anchors.** At 1-2 m
  spacing the four antennas mount on one rigid structure. Geometry is then
  fixed at manufacture to sub-millimetre, so there is **no install-time
  survey** (anchor position error otherwise feeds one-for-one into tag
  position error), cable lengths are fixed so the delay calibration stays
  valid, and the product is one unit rather than an installation job. **A0
  must be offset out of the plane of A1-A3** (20-30 cm on a standoff) --
  four coplanar antennas have a mirror ambiguity about that plane and
  degrade badly in elevation near it. Free at design time, impossible to
  retrofit.
- **UWB connectors: SMA.** CH5 at 6489.6 MHz is *above* the DC-6 GHz rating
  of U.FL, W.FL, MMCX and MCX; SMB is DC-4 GHz. SMA is DC-18 GHz. Prefer
  antennas with integral pigtails over a connector at each end -- every
  mated pair costs ~0.1-0.3 dB at 6.5 GHz plus a reflection. **The
  wristband's 2.4 GHz BLE U.FL (`J2`) is unaffected and stays** -- well
  inside rating, and the right choice for a wearable.
- ~~**Host MCU: ESP32-S3-WROOM-1 retained**, no second MCU.~~ **SUPERSEDED
  2026-09-19 by the Fanstel BT840** once the WiFi requirement was dropped --
  see that entry above. Kept for the reasoning, which still holds on its own
  terms: it was correct *while* WiFi was a requirement. Considered and
  rejected: switching to nRF52840 for native Qorvo driver support (loses
  WiFi, which is why the ESP32-S3 is there) and a dual-MCU split (permanent
  BOM, second toolchain, and an inter-MCU protocol to maintain, to avoid a
  one-time integration cost). A maintained ESP-IDF driver port exists
  (`br101/dw3000-decadriver-source`, wrapping Qorvo's own `dwt_uwb_driver`);
  its one-chip-per-board limitation is tracked under Open. MCU timing jitter
  does not affect accuracy -- timestamps are latched in hardware and read
  over SPI afterwards, and delayed-TX schedules transmissions in the chip.
  Four chips share one SPI bus with four chip selects; DW3000 runs to 36 MHz
  (20 MHz in CRC mode).
- **DW3000 variant: DW3210 (QFN40), not DW3110.** Per DW3000 Datasheet Table
  1, DW3110 is a **52-ball WLCSP, 3.1 x 3.5 mm** -- chip-scale, not
  realistically hand-assemblable. DW3210 is the same non-PDoA part in QFN40
  (5x5mm). Same hand-assembly reasoning already applied to the MAX17048
  TDFN-vs-WLP choice. Accepted tradeoff: the datasheet states QFN variants
  output about **2 dB less maximum TX power** than WLCSP. The PDoA variants
  (DW3120/DW3220) were considered and set aside -- PDoA on a single IC with
  two antenna ports is a different way to get bearing without cross-receiver
  synchronization, but it changes the whole architecture, and the team's call
  is the shared-clock TDoA array.
- **Wristband: one DWM3001C replaces NINA-B111 + DWM3000 + the whole antenna
  sheet.** Resolved 2026-09-19 after establishing that the tag's BLE radio
  serves no purpose in this system -- it talks only over UWB. Once BLE is not
  a requirement, the question stops being "which BLE module" and becomes
  "what is the simplest way to get a Cortex-M4 talking to a DW3110".

  The DWM3001C is exactly that in one part: DW3110 UWB transceiver, Nordic
  nRF52833 MCU, ST LIS2DH12 accelerometer, planar UWB antenna, Bluetooth chip
  antenna, power management and the 38.4MHz crystal. 48-pin side-castellated,
  27.1 x 19.13 x 3.2mm, VDD 2.5-3.6V. Its datasheet states it "requires no RF
  design as the antenna and associated analog and RF components are on the
  module" (Section 8).

  **Counterintuitively this is the simpler board, not the more complex one.**
  A discrete MCU would have meant a second part plus its crystal, decoupling,
  layout and an inter-chip SPI bus to design. Deleted instead: NINA-B111,
  DWM3000, `antenna.kicad_sch` in full (ProAnt InSide-2400, U.FL connector,
  L/C matching network), the GPIO5/6 SPI-mode straps R7/R8, and the R9 IRQ
  pulldown -- the host-to-transceiver link is internal now. Wristband went
  from 8 sheets to 6.

  **BLE and the accelerometer are deliberately unused.** They are dormant
  silicon on a module bought for its M4 and its UWB radio: no external parts,
  no wiring, no firmware. The accelerometer is worth revisiting as a way to
  motion-gate the UWB, which is the largest battery lever available on the
  power-constrained side of the system.

  Also true and not the reason: the LDO budget got easier (70mA -> 43mA,
  headroom 3.6x -> 5.8x), and the module ships factory-calibrated for crystal
  trim, TX power and antenna delay.

  Symbol hand-authored in `wristband/libs/` from the real DWM3001C Data Sheet
  Rev B (May 2022) Table 2. **Footprint not yet authored** -- the land pattern
  is in Figure 5, which does not extract as text; read the figure. Pin 18 is
  undocumented in Table 2 and is modelled as a passive NC -- confirm before
  fab.

  Superseded by this: the earlier NINA-B111 choice (u-blox NINA-B1-series
  external-antenna variant, datasheet UBX-15019243-R15) and its symbol and
  footprint, which stay in `wristband/libs/` unused for now.
- **UWB module (as currently drawn)**: Qorvo/Decawave **DWM3000** -- a bare
  UWB transceiver module with no onboard host MCU. Still correct for the
  wristband; superseded for the bay station by the discrete decision above.
  An earlier pass of this doc used the name "DWM3000C", which isn't a real
  Qorvo part number -- see `shared/README.md` for the correction writeup.
  Symbol in `shared/symbols/` (verified against Qorvo DWM3000 Data Sheet Rev
  B, May 2021); footprint is a flagged `DWM3000_PLACEHOLDER` pending one
  land-pattern dimension -- verify before fab.
- **Wristband BMS**: MCP73831 (LiPo linear charger) + DW01A/FS8205
  protection pair -- same proven pattern as the team's other wristband
  project (alarm-band). Symbols in `wristband/libs/`; battery connector and
  USB-C charging receptacle reuse KiCad's own default libraries.
- ~~**Bay station connectivity**: ESP32-S3-WROOM-1 module~~ -- **SUPERSEDED
  2026-09-19 by the Fanstel BT840**. The original reasoning (one part instead
  of discrete BLE+WiFi ICs) was sound, and the "revisit if 2.4GHz-only WiFi
  matters" caveat resolved in an unexpected direction: WiFi stopped being
  needed at all.
- **Bay station BMS**: MCP73871 (charge + power-path management, so the
  station can run continuously on external power while its battery tops off
  in the background) + MAX17048 fuel gauge (proven on alarm-band).
- **Repo structure**: monorepo, two KiCad projects (`wristband/`,
  `bay-station/`) + a `shared/` library folder. KiCad has no native
  multi-board project, and a monorepo keeps shared parts/docs/history in one
  place for a small team.
- **Voltage regulation** (a gap found by checking real datasheets: NINA-B111
  abs-max VCC is 3.9V, DWM3000 abs-max VDD3V3 is 4.0V, but a charged LiPo
  hits 4.2V -- both ICs were about to be fed straight off the unregulated
  battery/system rail with no margin against permanent damage):
  - Wristband: **TI TPS7A0233PDBVR** LDO (fixed 3.3V, SOT-23-5),
    `wristband/regulation.kicad_sch`. **Replaced Microchip MCP1700T-3302E/TT
    on 2026-09-23.** The regulator is still required (battery reaches 4.2V,
    DWM3001C tops out at 3.6V operating / 4.0V abs max), but the MCP1700's
    1.6uA typ / 4uA max quiescent current had become the largest single
    standby draw on the board -- more than the DWM3001C's own 850nA sleep.
    TPS7A02 is 25nA typ / 46nA max at 25C, 3nA shut down, and also improves
    accuracy to +/-1.5% over temperature. Board standby ~4.3uA -> ~2.7uA.
    Verified against TI SBVS277C.

    Trade-offs accepted: 200mA rating instead of 250mA, ~$0.78 instead of
    ~$0.16, and a 5-pin package with an EN input that must be tied high
    (TPS7A02 is disabled when EN floats; it cannot be GPIO-driven, because
    the MCU it powers cannot enable its own supply). A buck converter was
    considered and rejected -- at this load it trades a few points of
    efficiency for an inductor, higher Iq and switching noise next to a UWB
    receiver.

    Load re-run 2026-09-19 for the DWM3001C: module 40mA (CH5 TX or RX,
    DWM3001C Datasheet Rev B Table 5) + D3 status LED ~3mA = **~43mA**,
    against the TPS7A02's 200mA rating -- 4.6x headroom.

    **Open follow-up:** with the LDO down to tens of nA, the 2MOhm R11/R12
    battery-sense divider (~1.85uA) is now the dominant standby term.
  - Bay station: **TI TPS62A02PDDCR** buck converter (2A, single-cell-Li-Ion
    input range), `bay-station/regulation.kicad_sch`. Current budget:
    **Re-run 2026-09-19 for the discrete architecture**: ESP32-S3-WROOM-1
    (~355mA peak TX) + 4x DW3210 (72mA each, CH5 RX peak, DW3000 Datasheet
    v1.3 Table 5) + clock network (~27mA, estimated) + status LEDs (~12mA)
    = **~682mA vs. 2A rating, ~2.9x headroom**. The part choice survives;
    no regulator change needed. Full working in
    `bay-station/regulation_notes.md`. Re-check once the TCXO and clock
    buffer are actually selected -- those two lines are estimates.
- **Wristband antenna** -- ~~ProAnt InSide-2400 patch antenna on U.FL, chosen
  from u-blox's NINA-B1 approved-antenna list~~. **Superseded 2026-09-19**:
  the DWM3001C carries both its UWB and Bluetooth antennas on-module, so the
  external antenna, its U.FL connector, its matching network and the whole
  `antenna.kicad_sch` sheet were deleted. This also closed the open
  "matching-network values pending prototype RF tuning" item -- there is
  nothing left to tune.
- **DWM3000 GPIO5/GPIO6 SPI-mode strapping**: the power-up sequence requires
  these sampled at boot (per Qorvo's own timing diagrams) -- 10k pull-downs
  per instance (`wristband/radio_mcu.kicad_sch`;
  `bay-station/uwb_array.kicad_sch` x4).
- **ESP32-S3-WROOM-1 boot-strapping + programming**: pull resistors on
  GPIO0/3/45/46 per Espressif's real hardware design guidelines, an EN
  RC-delay network, BOOT/RESET buttons, and a native-USB flashing interface
  -- `bay-station/programming_debug.kicad_sch`. Surfaced the "two USB-C
  connectors" open item above.
- **Wristband programming**: standard 2x5 1.27mm ARM Cortex Debug SWD header,
  `wristband/programming_debug.kicad_sch`. Now targets the nRF52833 inside the
  DWM3001C via SWD_CLK (pin 2) and SWD_DIO (pin 3); unchanged otherwise.
- **KiCad version**: team standardizes on **KiCad 10.0.5** (current stable;
  supersedes an earlier, since-corrected plan to target 9.x). Files on disk
  are still KiCad 8.0 format -- re-checked and confirmed clean under 10.0.5
  via `kicad-cli` on 2026-08-14. See root `README.md`'s Toolchain section.
- **Passives audit against every chip's real reference design**: compiled in
  `passives-reference.md`. Found and fixed one real gap (100k IRQ/GPIO8
  pulldowns missing on all 5 DWM3000 instances, per Qorvo's own Figure 11 --
  added as R9 on the wristband, R25-R28 on the bay station). Also documented,
  not changed: DWM3000's placed decoupling exceeds Qorvo's own minimal
  application circuit (kept as conservative practice), and its GPIO5/6
  external straps are redundant with the chip's internal pulls (kept
  deliberately for tighter timing margin).

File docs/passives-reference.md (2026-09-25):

# Passive components reference, per chip

Compiled from each chip's own datasheet reference/typical-application
circuit -- not guessed. This is the definitive cross-reference for "what
does this IC need around it and why"; per-sheet component tables in each
board's `*_notes.md` are the more detailed originals this was compiled from.
All passives are standard **0603** (`R_0603_1608Metric` / `C_0603_1608Metric`
/ `L_0603_1608Metric`) unless noted otherwise.

## Qorvo DWM3001C (wristband, U3)

No reference/application circuit exists for this part. It is a certified
module with on-board power management, its own 38.4MHz crystal, and both
antennas integrated -- the datasheet is explicit that it "requires no RF
design as the antenna and associated analog and RF components are on the
module" (Section 8). There is nothing external to add beyond supply
decoupling.

| Passive | Value | Role | Status |
|---|---|---|---|
| C6 | 100nF | VDD (pin 12) bypass | Placed (`radio_mcu.kicad_sch`). Conservative standard practice; Qorvo publishes no external application circuit, so there is no datasheet value to confirm against. |
| C7 | 10uF | VDD bulk | Placed (`radio_mcu.kicad_sch`). Same basis as C6. |

**Superseded:** this section previously covered u-blox NINA-B111 (C6/C7 as
VCC/VCC_IO bypass) and an L1/C13 DNP antenna matching network on
`antenna.kicad_sch`. Both parts and that whole sheet were deleted on
2026-09-19 when the wristband consolidated onto the DWM3001C -- see
`decisions.md`. The matching network no longer exists, so neither does the
open RF-tuning task attached to it.

## Qorvo DWM3000 (wristband U4; bay-station U4-U7, x5 total)

Real "Example DWM3000 Application Circuit" (datasheet Rev B, Figure 11,
Section 6.2) shows the module needs **only power + host connection** -- no
external decoupling caps drawn on VDD1/VDD3V3/VDD3V3 at all, since the
module has its own integrated regulation/crystal.

| Passive | Value | Role | Status |
|---|---|---|---|
| Decoupling caps (per instance) | 100nF/100nF/1uF (wristband: C8-C10; bay-station: C11-C19, 3 per anchor) | VDD1/VDD3V3/VDD3V3 bypass | Placed, **beyond what Qorvo's own minimal example circuit shows**. Not wrong (extra bypass capacitance on a supply rail is standard conservative practice), but worth knowing it's a "belt and suspenders" addition, not a datasheet mandate. |
| GPIO5/GPIO6 pull-downs (per instance) | 10k (wristband: R7/R8; bay-station: R10-R17, 2 per anchor) | SPI-mode boot strapping ("Sample GPIOs 5&6 to set SPI mode", Figures 1/2) | Placed. **Technically redundant** -- the chip's own GPIOs default to internal pull-down (10-30k, varies with VDD1) out of reset, per Section 6.3, so the strap would resolve correctly even with nothing external. Kept deliberately for tighter/more deterministic timing margin than the chip's own variable internal pull, not because it's strictly required. |
| IRQ/GPIO8 pull-down (per instance) | **100k** (wristband: R9; bay-station: R25-R28) | "Optional pulldown on IRQ to prevent spurious interrupts" -- explicitly shown in Figure 11 | **Newly added this pass** -- was missing from the design entirely until this audit. |
| RSTn | -- (open-drain from host) | Reset | Figure 11 shows this driven from an open-drain host GPIO with no external pull shown -- not yet wired (placement-only stage), nothing to add here. |

No external crystal needed -- the module has its own onboard 38.4MHz
reference crystal (Section 1.1), confirmed, not something to source.

## Microchip MCP73831 (wristband charger, U2)

Real typical application circuit, DS20001984G/H, page 1 ("500mA Li-Ion
Battery Charger").

| Passive | Value | Role | Status |
|---|---|---|---|
| R4 | 6.8k | PROG -- sets ~147mA fast-charge current (`IREG[mA] = 1000/RPROG[kΩ]`) | Placed |
| C2 | 4.7uF | VDD input decoupling (datasheet's exact shown value) | Placed |
| C3 | 4.7uF | VBAT output decoupling (datasheet's exact shown value) | Placed |
| R5, R6 | 5.1k | USB-C CC1/CC2 pull-downs (not part of the charger IC itself, but needed to source its VDD from a real USB-C port) | Placed |

## Fortune Semiconductor DW01A + FS8205 (wristband protection, U1 + Q2)

Real typical application circuit, DW01A-DS-11/12_EN, Section 8/page 5.

| Passive | Value | Role | Status |
|---|---|---|---|
| R2 | 100Ω | Cell+ to DW01A VCC feed (datasheet's own "R1") | Placed |
| C1 | 0.1uF | DW01A VCC-to-GND decoupling (datasheet's own "C1") | Placed |
| R3 | 1k | DW01A CS pin to post-FET GND, current-sense (datasheet's own "R2") | Placed |

No passives needed around FS8205 itself beyond what's shared with DW01A above
-- it's driven directly by DW01A's OD/OC outputs.

## AOS AO3401A (both boards, reverse-polarity "ideal diode" FET)

Not a datasheet-specified reference circuit (this is a general-purpose
technique, not an AOS application note) -- gate-pulldown value is a design
choice, not derived from a table.

| Passive | Value | Role | Status |
|---|---|---|---|
| Gate pull-down (wristband R1; bay-station R1) | 100k | Biases the FET off if the gate is ever undriven; value not critical, just needs to be much larger than the FET's own gate leakage | Placed |

## onsemi ESD5B5.0ST1G (TVS, both boards -- 1x wristband, 3x bay-station)

Standalone protection part -- no supporting passives required by its own
datasheet; used directly across the rail it protects.

## Fanstel BT840 / Nordic nRF52840 (bay-station connectivity, U3)

Replaced the ESP32-S3-WROOM-1 on 2026-09-19. The BT840 is a certified module
with on-board DC-DC and its own antenna, so there is no external application
circuit to work from -- C5/C6/C7 on `connectivity.kicad_sch` are conservative
3V3 supply decoupling, not datasheet-specified values.

## Qorvo DW3210 (bay-station uwb_array, U4-U7, x4)

**Decoupling is deliberately NOT yet placed.** The previous C8-C19 were sized
for a DWM3000 module with a single VDD3V3 rail and do not map onto a bare IC.
The DW3210 has three separate supply rails -- VDD1 (pin 29, main + I/O),
VDD2a/VDD2b (28/23) and VDD3 (26) -- **plus two decoupling-only pins**,
VTX_D (27) and VIO_D (38), which each need their own capacitor to ground and
must NOT be tied to a rail. Re-derive the whole set from the DW3000 datasheet
before wiring.

Also required per anchor and already placed: 10k GPIO5/GPIO6 SPI-mode straps
(R10-R17) and a 100k IRQ pull-down (R25-R28, Qorvo Figure 11). RF1 (pin 18)
needs a series 2pF cap; RF2 (pin 13) is unused on this non-PDoA variant and
must be terminated into 50 ohm through a 50 ohm trace.

## Espressif ESP32-S3-WROOM-1 -- HISTORICAL (superseded by the BT840)

Decoupling per Espressif's hardware design guidelines; boot-strap resistors
per the real datasheet Section 4/Table 4-1/4-3/4-4/4-5; EN RC delay per the
separate ESP32-S3 Hardware Design Guidelines "Schematic Checklist".

| Passive | Value | Role | Status |
|---|---|---|---|
| C5 | 10uF | Bulk decoupling | Placed (`connectivity.kicad_sch`) |
| C6, C7 | 100nF | Bypass | Placed |
| R18 | 10k, pull-up | GPIO0 -> SPI Boot mode (explicit, matches default weak internal pull) | Placed (`programming_debug.kicad_sch`) |
| R19 | 10k, pull-down | GPIO3 -- datasheet requires an external pull here, "does not have any internal pull resistors" | Placed |
| R20 | 10k, pull-down | GPIO45 -- selects 3.3V VDD_SPI (matches this module's flash variant) | Placed |
| R21 | 10k, pull-down | GPIO46 -- avoids an explicitly-called-out invalid strap combination | Placed |
| R22 + C23 | 10k / 1uF | EN pin RC delay, exact values from Espressif's own recommendation | Placed |
| SW1, SW2 | -- | BOOT / RESET tactile buttons | Placed |

## Microchip MCP73871 (bay-station charge/power-path, U1)

Real typical application circuit + Sections 3-5, DS20002090E, page 2.

| Passive | Value | Role | Status |
|---|---|---|---|
| R2 (PROG1) | 2.00k | Sets 500mA fast-charge current (`IREG[mA] = 1000/RPROG1[kΩ]`, Eq. 4-1) | Placed |
| R3 (PROG3) | 20.0k | Sets 50mA termination current, 10:1 ratio (Eq. 4-2) | Placed |
| R4/R5 (VPCC divider) | 330k / 110k | Power-path priority threshold, datasheet's own worked example (Section 3.3) | Placed |
| TH1 | 10k NTC | THERM battery-temperature bias (typical application circuit) | Placed |
| C1 | 10uF | IN decoupling (datasheet diagram's shown value; Section 3.1's stated *minimum* is 4.7uF) | Placed -- flagged: 10uF in an 0603 case may be tight to source at a real working voltage rating, verify at BOM time |
| C2 | 4.7uF | OUT/+VSYS decoupling | Placed |
| C3 | 4.7uF | VBAT/VBATT_PROT decoupling | Placed |

Strap pins (SEL, PROG2, TE, CE) are tied directly to logic rails, not through
passives -- see `bay-station/power_bms_notes.md` for the full reasoning.

## Maxim/ADI MAX17048 (bay-station fuel gauge, U2)

Per the datasheet's "Simplified Operating Circuit."

| Passive | Value | Role | Status |
|---|---|---|---|
| C4 | 0.1uF | VDD decoupling (datasheet's typical operating circuit value) | Placed |

CTG tied to GND, QSTRT tied to GND, CELL left unconnected (correct for the
single-cell MAX17048 variant) -- no passives involved in any of those three.

## TI TPS7A0233PDBVR (wristband LDO, U5)

Real datasheet TI SBVS277C. Replaced the Microchip MCP1700T-3302E/TT on
2026-09-23 (`decisions.md`); the MCP1700's 1.6uA Iq had become the board's
largest standby draw.

| Passive | Value | Role | Status |
|---|---|---|---|
| C11 (Cin) | 1uF X7R | Input decoupling | Placed (`regulation.kicad_sch`) |
| C12 (Cout) | 2.2uF X7R | Output decoupling -- SBVS277C S6.3. **Sized up from the MCP1700's 1uF**, so don't "restore" it | Placed |

Note this part has an **EN pin that must be tied high** (pin 3). It is
disabled when EN floats, and it cannot be GPIO-gated, because the MCU it
powers cannot enable its own supply. Pin 4 is NC. The package is SOT-23-**5**
-- the PCB carried a 3-pad SOT-23 for it until 2026-09-25.

**Superseded:** this section previously covered the MCP1700T-3302E/TT with
C11/C12 both at 1uF X7R, from that part's page-2 "Typical Application
Circuit." The older MCP1700 walkthrough still sitting in
`../wristband/regulation_notes.md` under "Capacitors: C11 (Cin), C12 (Cout)"
is stale for the same reason and should be rewritten.

## TI TPS62A02PDDCR (bay-station buck, U8)

Real datasheet Table 8-2/8-3 component recommendations + Eq. 2 for the
feedback divider.

| Passive | Value | Role | Status |
|---|---|---|---|
| L1 | 1uH | Power inductor (Table 8-3) | Placed (`regulation.kicad_sch`) -- **no KiCad-default footprint exists** for the chosen Coilcraft XGL3520-102MEC; source a real footprint at BOM time (open item, `docs/decisions.md`) |
| C20 (Cin) | 4.7uF, 0805 | Input decoupling (Table 8-2, sized up from 0603 for DC-bias derating) | Placed |
| C21 (Cout) | 22uF, 0805 | Output decoupling (Table 8-3's recommended pair for VOUT>=1.8V) | Placed |
| C22 | 120pF | Optional feedforward cap across R8, reduces PSM ripple (datasheet's own note) | Placed |
| R8 | 453k | FB divider top -- sets VOUT=3.318V (Eq. 2 math, nearest E96 value) | Placed |
| R9 | 100k | FB divider bottom -- at the datasheet's own stated ceiling for acceptable noise sensitivity | Placed |

## Summary: what changed this pass

- **Added** (previously missing): 100kΩ IRQ/GPIO8 pulldowns on all 5 DWM3000
  instances (R9 wristband; R25-R28 bay-station), per Qorvo's own Figure 11.
- **Confirmed, not changed**: DWM3000's per-instance decoupling caps go
  beyond Qorvo's own minimal example circuit (which shows none) -- kept as
  reasonable conservative practice, documented rather than removed.
- **Confirmed, not changed**: DWM3000's GPIO5/6 external strap resistors are
  redundant with the chip's own internal default pulls, kept deliberately
  for tighter timing margin.
- Everything else in this document was already resolved and placed in
  earlier passes -- this compile just brings it all into one place and
  verifies nothing was missed against each chip's real reference design.

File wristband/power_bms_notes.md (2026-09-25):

# `power_bms.kicad_sch` -- design notes

> **SUPERSEDED IN PART — 2026-09-15.** This document records the analysis pass that
> was done when the wristband's BLE MCU was the **u-blox NINA-B111** (nRF52832) and the
> antenna fed through a PCB-side U.FL connector (`J2`) and an L/C matching network
> (`L1`/`C13`). The board has since migrated to the **u-blox NINA-B400** (nRF52833,
> Bluetooth 5.1), whose on-module U.FL connector made `J2`, `L1` and `C13` unnecessary —
> all three were removed. The reasoning and datasheet citations below are kept verbatim
> as the historical record of *how* those decisions were reached; where they name
> NINA-B111, read the conclusion as applying to NINA-B400 unless noted otherwise.
> Two things deliberately carry over unchanged, both re-verified against the NINA-B40
> data sheet UBX-19049405 R09: the **3.9 V abs-max VCC** (identical on both modules, so
> the MCP1700 LDO rationale still stands) and the **SWD pin numbers** (SWDCLK=11,
> SWDIO=15, RESET_N=19, SWO=8 on both). See `../docs/decisions.md` for the current state.

Hierarchical sub-sheet covering the wristband's battery input, reverse-polarity
protection, single-cell over-charge/discharge/current protection, and Li-Po
charging. Wired into `wristband.kicad_sch` as a sheet symbol (Sheetname
"Power BMS", uuid `e17e6f9a-2b41-4d3a-9f0a-1c1f5c9a7b21`) and registered in
`wristband.kicad_pro`'s `sheets` list. No wires are drawn anywhere on this
sheet -- every net is carried by a `global_label` placed exactly on top of
the pin it belongs to (same convention as the sibling wristband-alarm
project's `power.kicad_sch`).

## Component-by-component

| Ref | Part | lib_id | Datasheet | Notes |
|---|---|---|---|---|
| BT1 | Generic single-cell LiPo, 2-pin JST-PH | `Device:Battery_Cell` (footprint `Connector_JST:JST_PH_S2B-PH-K_1x02_P2.00mm_Horizontal`) | n/a (generic connector) | Matches `wristband/libs/components.csv` row 6 -- the part already identified for this project. |
| Q1 | Alpha & Omega Semiconductor AO3401A, P-channel MOSFET, SOT-23 | `Transistor_FET:AO3401A` | http://www.aosmd.com/pdfs/datasheet/AO3401A.pdf | Reverse-battery-polarity protection ("ideal diode"). Pinout (1=Gate, 2=Source, 3=Drain) verified against AOS's real datasheet and cross-checked via web search (LCSC/Digikey/alltransistors listings all agree). See "P-MOSFET reverse-polarity protection" below for why this part and the wiring rationale. |
| R1 | 100k&Omega;, 0603 | `Device:R` | n/a (generic passive) | Q1 gate pull-down to `GND` (system ground, downstream of the FS8205A pass FETs) -- standard value for this "ideal diode" gate bias; not current-critical, just needs to be >> the FET's own gate leakage and << load impedance. |
| D1 | onsemi ESD5B5.0ST1G, bidirectional TVS, SOD-523 | `Device:D_TVS` (footprint `Diode_SMD:D_SOD-523`) | https://www.onsemi.com/pdf/datasheet/esd5b5.0st1-d.pdf | Across `VBAT`-`GND` (protected battery rail, post-Q1). 5.0V standoff / 5.8-7.8V breakdown / ~9.2V typ. clamping -- comfortably above the 4.2V max charge voltage (MCP73831-**2** variant) with margin, while still clamping well below the FS8205A's 20V VDS rating. Same part family already used for VBUS ESD protection in `components.csv` row 8; reused here for the battery rail specifically because it's a real, well-documented, commonly-stocked part in the right standoff-voltage class for a 1S Li-ion/LiPo cell (see task item 3: "5-6V class commonly used for LiPo protection"). |
| U1 | Fortune Semiconductor DW01A, SOT-23-6 | `wristband:DW01A` (already in `libs/wristband.kicad_sym`, untouched) | http://www.ic-fortune.com/upload/Download/DW01A-DS-12_EN.pdf | Single-cell protection IC. Wiring below replicates Fortune's own "Typical Application Circuit" (datasheet Rev 1.1, page 5) pin-for-pin. |
| R2 | 100&Omega;, 0603 | `Device:R` | (part of U1's own datasheet app circuit) | This is the datasheet's own "R1" -- VCC feed resistor between `VBAT` and DW01A's VCC pin (renamed `R2` here to avoid clashing with the reverse-polarity gate resistor `R1`). |
| C1 | 0.1uF, 0603 | `Device:C` | (part of U1's own datasheet app circuit) | This is the datasheet's own "C1" -- VCC-to-GND decoupling for U1, but note "GND" here is `CELL_N` (raw cell negative, *before* the FS8205A pass FETs), matching exactly where the datasheet draws it (same node as U1's own GND/TD pins), not the downstream system `GND` net. |
| R3 | 1k, 0603 | `Device:R` | (part of U1's own datasheet app circuit) | This is the datasheet's own "R2" -- between DW01A's CS (current-sense) pin and system `GND` (post-FET pack negative), sensing the voltage drop across the two series pass FETs for overcurrent detection. |
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

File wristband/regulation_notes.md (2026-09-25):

# Regulation / Antenna / Programming-Debug -- design notes

> **SUPERSEDED IN PART — 2026-09-23.** The wristband has migrated again, this time
> from the two-chip **NINA-B400 + DWM3000** pair to a single **Qorvo DWM3001C**
> module, which integrates the DW3110 UWB transceiver, the same Nordic nRF52833
> BLE MCU, an ST LIS2DH12 accelerometer, a 38.4 MHz reference crystal, a UWB
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

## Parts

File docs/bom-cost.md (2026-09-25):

# BOM cost estimate

Rough build cost for **one prototype pair** (one wristband + one bay station),
at quantity-one hobbyist pricing. Compiled 2026-09-19.

## How to read this

Each board's authoritative part-by-part BOM is its own
`<board>/libs/components.csv` -- part numbers, symbols, footprints, datasheet
URLs, and verification notes. **This document is the money view only**, and it
deliberately does not duplicate that detail.

Prices are marked:

- **[V]** verified against a distributor listing, with the date
- **[E]** estimate -- order of magnitude, for planning only

Nobody should order from this table. It exists so the team knows whether this
is a $100 project or a $1000 one before committing, and so the expensive
lines are visible early.

## Wristband

| Item | Qty | Unit | Ext | |
|---|---|---|---|---|
| Qorvo DWM3001C module | 1 | $38 | $38 | [E] -- replaces NINA-B111 + DWM3000 + antenna |
| LiPo cell | 1 | $8 | $8 | [E] |
| PCB, 4-layer, small, qty-5 order | 1 | $10 | $10 | [E] |
| SWD header, 2x5 1.27mm | 1 | $1.50 | $1.50 | [E] |
| MCP73831 charger | 1 | $0.70 | $0.70 | [E] |
| MCP1700T-3302E/TT LDO | 1 | $0.50 | $0.50 | [E] |
| DW01A + FS8205 protection pair | 2 | $0.30 | $0.60 | [E] |
| AO3401A, ESD5B5.0ST1G | 2 | $0.35 | $0.70 | [E] |
| USB-C receptacle, JST-PH | 2 | $0.65 | $1.30 | [E] |
| Status LEDs 0603 (D2, D3) | 2 | $0.15 | $0.30 | [E] |
| Passives, ~25x 0603 | 25 | $0.05 | $1.25 | [E] |
| | | | **~$67** | |

## Bay station

| Item | Qty | Unit | Ext | |
|---|---|---|---|---|
| **Coax assemblies, 1-2 m, SMA both ends** | 4 | $15 | **$60** | [E] -- see note |
| Qorvo DW3210 (DW3210TR13) | 4 | $10.45 | $41.80 | **[V]** DigiKey, Sept 2026 |
| PCB, 4-layer **controlled impedance**, qty-5 | 1 | $40 | $40 | [E] |
| UWB antennas (Taoglas UWC.01 class) | 4 | $8 | $32 | [E] |
| Rigid antenna frame (fabrication) | 1 | $30 | $30 | [E] |
| SMA board connectors | 4 | $2.50 | $10 | [E] |
| Li-Ion cell | 1 | $10 | $10 | [E] |
| Fanstel BT840 (nRF52840) | 1 | $6.88 | $6.88 | **[V]** Fanstel, Sept 2026 -- replaced ESP32-S3-WROOM-1 (~$3.50) |
| MAX17048 fuel gauge | 1 | $3 | $3 | [E] |
| 38.4 MHz TCXO | 1 | $3 | $3 | [E] |
| 1:4 low-skew clock buffer | 1 | $2.50 | $2.50 | [E] |
| MCP73871 power-path charger | 1 | $2 | $2 | [E] |
| TPS62A02PDDCR + XGL3520 inductor | 2 | $1.20 | $2.40 | [E] |
| Barrel jack, 2x USB-C | 3 | $1 | $3 | [E] |
| AO3401A, 2x ESD5B5.0ST1G | 3 | $0.35 | $1.05 | [E] |
| Tactile buttons | 2 | $0.30 | $0.60 | [E] |
| Status LEDs 0805 (D4-D7) | 4 | $0.15 | $0.60 | [E] |
| u-blox MAX-M10S GNSS | 1 | $12 | $12 | [E] |
| Active GNSS antenna, SMA | 1 | $10 | $10 | [E] -- not yet selected |
| LIS3MDL magnetometer + LIS2DH accelerometer | 2 | $2 | $4 | [E] |
| Passives, ~55x 0603/0805 | 55 | $0.05 | $2.75 | [E] |
| | | | **~$278** | |

**System total: roughly $345 for one prototype pair.**

## Wristband consolidation (2026-09-19)

The wristband line above is one module where it used to be four items. Moving
to the DWM3001C removed NINA-B111 (~$12), DWM3000 ($28.34 [V]), the ProAnt
antenna (~$5) and the U.FL connector (~$1) -- about **$46** -- and added one
module estimated at **$38**. Roughly a wash on cost, and that is the point:
the saving was never the argument. What it actually bought was one part
instead of four, two fewer schematic sheets, no inter-chip SPI to design, no
RF matching network to tune, a free accelerometer, and Qorvo reference
firmware for the exact module.

**The $38 is an estimate and the weakest number in this document** -- I could
not find qty-1 pricing. Get a real quote before planning around it.

## Georeferencing (2026-09-23)

GNSS, magnetometer, accelerometer and an antenna add about **$26**. Worth
noting all three ICs are KiCad stock symbols AND footprints, so they add no
footprint-import work -- unlike the BT840 and DWM3001C. u-blox SAM-M10Q with
its integrated patch antenna would have deleted the $10 antenna line, but
KiCad has neither symbol nor footprint for it, so it would have traded $10
of BOM for a third outstanding vendor import.

## Two things the table makes obvious

**The RF interconnect is the single biggest cost, not the silicon.** Coax,
antennas, SMA connectors and the frame come to about **$132** -- more than
half the bay station, and over five times what the four transceivers cost.
That is the real price of the architecture, and it is worth knowing before
anyone optimises a $0.05 passive. It also means the coax choice is a genuine
cost/performance decision, not just an electrical one.

**Going discrete made the silicon cheaper, not more expensive.** This is
counterintuitive and worth recording:

| | Unit | x4 |
|---|---|---|
| DWM3000 module | $28.34 **[V]** | $113.36 |
| DW3210 IC | $10.45 **[V]** | $41.80 |
| | | **saves $71.56** |

So the discrete decision costs roughly $132 in RF interconnect and ~$30 in
extra PCB, offset by ~$72 saved on transceivers. Net, call it **$90 extra**
for a design that can actually do TDoA -- against a module-based design that
provably cannot, at any price.

And because this is a **university prototype with no certification
requirement** (see `decisions.md`), the item that would normally dominate
this comparison -- FCC/CE testing for an intentional radiator -- is simply
not a line item.

## Not costed here

- **Dev kits.** Strongly recommended and not in the table above. Both boards
  are now Nordic, so an nRF52840 DK plus a DWM3001CDK would cover tag and
  station firmware before any custom board exists -- and Qorvo's reference
  stack targets exactly that combination.
- **Assembly.** Assumes hand assembly. The DW3210 is QFN40 at 0.4 mm pitch --
  doable with a stencil and hot plate, but it is the hardest part on either
  board, and a reflow failure on a $10.45 part that then needs rework is a
  real cost in time.
- **Iteration.** First boards are rarely the last. Budget at least two spins.
- **Test equipment.** Array calibration needs a way to place the tag at
  surveyed positions to better than the accuracy you are trying to achieve.
  Depending on how that is done it could be free or could dominate everything
  above.
- **Enclosure.** Decided 2026-09-23 but neither selected nor costed. It has
  to be RF-transparent or it blocks the BT840 on-module BLE antenna, which
  rules out the cheap metal-box option. Plus the antenna frame beyond it, and
  cabling/PSU odds and ends.

## Before ordering

Every **[E]** row needs a real quote. The two that matter most, because they
are big and because the estimates behind them are the weakest:

1. **Coax assemblies** -- $60 is a guess, and the same guess drives the
   loss-per-metre figure that sets how much link margin you spend. Price and
   loss-spec these together. Note a longer baseline costs little electrically
   (~1 dB/m against ~17 dB of margin) but buys accuracy directly -- if the
   frame can be larger, the cable line item is the wrong place to economise.
2. **Controlled-impedance 4-layer PCB** -- $40 for a qty-5 order varies a lot
   by vendor and by stackup. DW3000 Section 7.3 constrains the stackup (see
   `positioning.md`), and as of 2026-09-23 it is set in the board file:
   35um copper throughout, 254um prepreg / 400um core / 254um prepreg,
   **1.048 mm finished**. That is deliberately the datasheet's own figure and
   **not a catalogue thickness** -- fabs quote 1.0 or 1.2 mm 4-layer, so
   expect to work to their nearest stackup and re-solve the 50 ohm trace
   widths against their real dielectric numbers. Get quotes against the
   actual spec, not a generic 4-layer, and ask for the impedance-control
   surcharge separately.

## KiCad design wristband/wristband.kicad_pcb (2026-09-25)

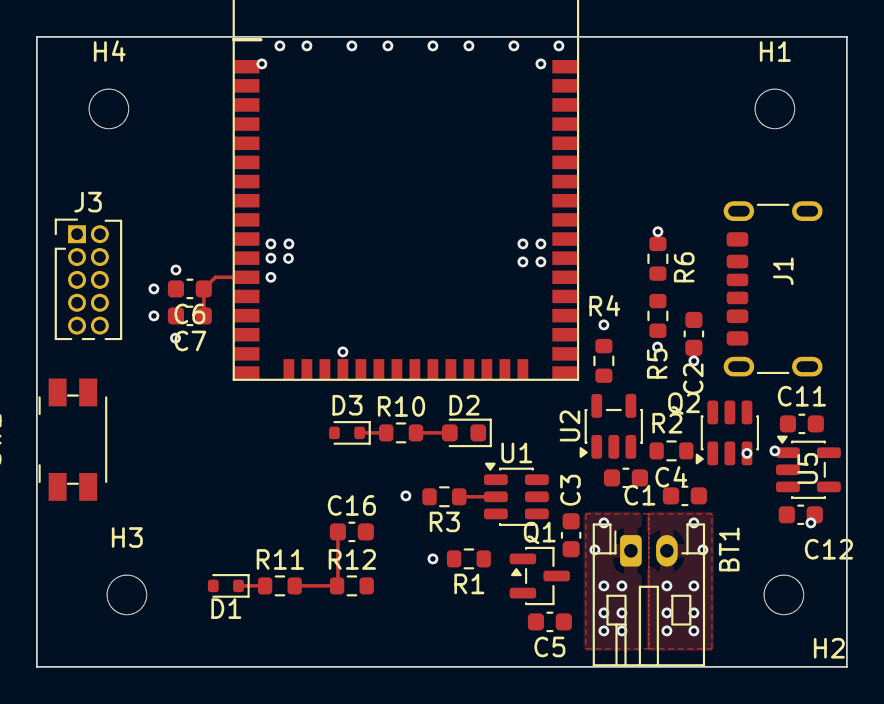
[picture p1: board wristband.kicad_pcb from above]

Board: 4 copper layers, 45.0 x 35.0 mm, 36 parts (0 on the bottom side), 23 nets.

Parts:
BT1: 3.7V LiPo (1S, JST-PH 2-pin); JST_PH_S2B-PH-K_1x02_P2.00mm_Horizontal
C1: 0.1uF; C_0603_1608Metric
C2, C3, C7: 4.7uF; C_0603_1608Metric
C4: 10uF; C_0603_1608Metric
C5, C6, C16: 100nF; C_0603_1608Metric
C11: 1uF; C_0603_1608Metric
C12: 2.2uF; C_0603_1608Metric
D1, D3: ESD5B5.0ST1G; D_SOD-523
D2: Green; LED_0603_1608Metric
H1, H2, H3, H4: M2; MountingHole_2.2mm_M2
J1: USB4125-GF-A; USB_C_Receptacle_GCT_USB4125-xx-x_6P_TopMnt_Horizontal
J3: Conn_ARM_JTAG_SWD_10; PinHeader_2x05_P1.27mm_Vertical
Q1: AO3401A; SOT-23
Q2: FS8205A; SOT-23-6
R1: 100k; R_0603_1608Metric
R2: 100; R_0603_1608Metric
R3, R10: 1k; R_0603_1608Metric
R4: 6.8k; R_0603_1608Metric
R5, R6: 5.1k; R_0603_1608Metric
R11, R12: 1M; R_0603_1608Metric
SW1: SOS; Panasonic_EVQPUJ_EVQPUA
U1: DW01A; SOT-23-6
U2: MCP73831T-2ACI/OT; SOT-23-5
U4: DWM3001C; DWM3001C_PLACEHOLDER
U5: TPS7A0233PDBVR; SOT-23-5

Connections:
+3V3: C6.1, C7.1, C12.1, J3.1 (VTref), U4.12 (VDD), U5.5 (OUT)
/Radio MCU/SOS_BNT: SW1.1, U4.6 (P0.17)
CC1: J1.A5 (CC1), R5.1
CC2: J1.B5 (CC2), R6.1
CELL_N: BT1.2 (-), C1.2, Q2.1 (S1), U1.4 (TD), U1.6 (GND)
CELL_P: BT1.1 (+), Q1.2 (S)
CHG_PROG: R4.1, U2.5 (PROG)
CHG_STAT: D2.1 (K), U2.1 (STAT)
DW01A_VCC: C1.1, R2.2, U1.5 (VCC)
FS_D12: Q2.2 (D12), Q2.5 (D12)
GND: C2.2, C3.2, C4.2, C5.2, C6.2, C7.2, C11.2, C12.2, C16.2, D1.2 (A2), D3.2 (A2), J1.A12 (GND), J1.B12 (GND), J1.SH (SHIELD), J3.3 (GND), J3.5 (GND), J3.9 (GNDDetect), Q2.3 (S2), R1.2, R3.2, R4.2, R5.2, R6.2, R12.2, SW1.2, U2.2 (VSS), U4.1 (GND), U4.11 (GND), U4.21 (GND), U4.38 (GND), U4.48 (GND), U5.2 (GND)
unnamed: D2.2 (A), R10.2
PROT_CS: R3.1, U1.2 (CS)
PROT_OC: Q2.4 (G2), U1.3 (OC)
PROT_OD: Q2.6 (G1), U1.1 (OD)
Q1_GATE: Q1.1 (G), R1.1
RESET_N: J3.10 (~RESET), U4.47 (RESET)
SWDCLK: J3.4 (SWCLK/TCK), U4.2 (SWD_CLK)
SWDIO: J3.2 (SWDIO/TMS), U4.3 (SWD_DIO)
SWO: J3.6 (SWO/TDO), U4.28 (P1.00)
VBAT: C3.1, C4.1, C5.1, C11.1, D1.1 (A1), Q1.3 (D), R2.1, R11.1, U2.3 (VBAT), U5.1 (IN), U5.3 (EN)
VBAT_SENSE: C16.1, R11.2, R12.1, U4.46 (P0.02)
VBUS: C2.1, D3.1 (A1), J1.A9 (VBUS), J1.B9 (VBUS), R10.1, U2.4 (VDD)

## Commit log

2026-08-14 Scaffold uwb-rescue-locator: monorepo with wristband + bay-station KiCad projects
    - wristband/ and bay-station/ are separate KiCad 8.0 projects (blank
    schematic + PCB, ERC/DRC clean), since KiCad has no native multi-board
    project support
    - shared/ holds symbols/footprints/3D models used on both boards, wired
    into each project's fp-lib-table/sym-lib-table via ${KIPRJMOD} relative
    paths so it works regardless of clone location
    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
    [bay-station.kicad_pcb, bay-station.kicad_sch, wristband.kicad_pcb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]
2026-08-15 Import real symbols/footprints for confirmed components
    Sourced against primary datasheets (not memorized/guessed pinouts), per
    part:
    - NINA-B111 (wristband MCU/radio): real symbol + footprint, pad geometry
    from u-blox's own official Eagle library, cross-checked against the
    datasheet mechanical table. No PLACEHOLDER needed.
    - DWM3000 (shared UWB module, wristband + 4x bay-station anchors): real
    symbol. Footprint flagged _PLACEHOLDER -- one land-pattern dimension
    didn't cleanly resolve from the datasheet figure. Note: corrected from
    an earlier, incorrect 'DWM3000C' (not a real Qorvo part number) after
    user clarification -- see docs/decisions.md and shared/README.md.
    - MCP73831 +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
2026-08-15 Add Power/BMS sheets: reverse-polarity protection, TVS, decoupling
    Wristband power_bms.kicad_sch:
    - JST-PH battery in -> AO3401A P-MOSFET reverse-polarity 'ideal diode'
    (source=batt+, gate pulled to GND via 100k) -> ESD5B5.0ST1G TVS across
    VBAT-GND -> DW01A+FS8205A single-cell protection (wired per Fortune
    Semiconductor's real datasheet application circuit) -> MCP73831 charger
    (USB-C power-only in, 6.8k PROG -> ~147mA, datasheet-exact CIN/COUT)
    - NINA-B111/DWM3000 deliberately deferred to a future radio_mcu sheet
    (this sheet just produces a decoupled VBAT rail) -- see
    wristband/power_bms_notes.md
    - ERC: 0 errors, 1 cosmetic warning (documented below)
    Bay-station power_bms.kicad_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
    [bay-station.kicad_sch, power_bms.kicad_sch, wristband.kicad_sch]
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2026-08-15 Add radio_mcu/mechanical (wristband) and connectivity/uwb_anchors/mechanical (bay-station) sheets
    Placement-only pass, nothing wired (no wires, no global labels) -- per
    request, this organizes the remaining confirmed components onto their
    own hierarchical sheets rather than wiring them up yet:
    Wristband:
    - radio_mcu.kicad_sch: NINA-B111 (U3) + DWM3000 (U4), with 0603 decoupling
    caps placed near each supply pin (values are reasonable generic
    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
    [bay-station.kicad_sch, connectivity.kicad_sch, mechanical.kicad_sch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]
2026-08-15 Audit BOM docs, add 0-ohm resistor entries, rewrite README status for handoff
    BOM audit (cross-checked every lib_id actually placed on every schematic
    sheet against each board's components.csv):
    - wristband/libs/components.csv was missing rows for the AO3401A reverse-
    polarity P-MOSFET and the mounting holes entirely, and its old TVS row
    described 'USB VBUS' when what's actually placed (D1) is on the battery
    line -- added/corrected all three.
    - bay-station/libs/components.csv was missing a mounting-holes row --
    added (M3, not M2 -- confirmed against the actual footprint placed).
    - Both CSVs now re-validated as well-formed (consistent 6-column rows;
    a couple of my own new rows had u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
2026-08-15 Add regulation/antenna/programming-debug sheets; fix confirmed voltage-safety gap
    Real datasheet check found a genuine hardware bug in progress, not just a
    missing part: NINA-B111 abs-max VCC is 3.9V, DWM3000 abs-max VDD3V3 is
    4.0V, but a fully-charged LiPo hits 4.2V -- both boards were about to feed
    these ICs straight off the unregulated battery/system rail. Fixed via a
    new dedicated regulation sheet per board (placement-only, not wired yet,
    same as everything else at this stage):
    - wristband/regulation.kicad_sch: MCP1700T-3302E/TT LDO (3.3V, low-Iq),
    current budget verified (NINA-B111 ~12mA + DWM3000 ~55mA vs 250mA
    rating, ~3.7x headroom)
    - bay-station/regulation.kicad_sch: TPS62A02PD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
    [antenna.kicad_sch, bay-station.kicad_sch, programming_debug.kicad_sch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]
2026-08-16 Add contributor setup guide and Claude Code / agent usage notes to README
    New 'Getting started' section: KiCad install (brew/downloads), no
    per-machine config needed thanks to ${KIPRJMOD} relative lib paths, repo
    access + clone, opening a board (no single top-level project), and a
    kicad-cli sanity check to confirm setup worked.
    New 'Using Claude Code (or another coding agent)' section, right after
    Toolchain: documents the tooling patterns and gotchas actually
    encountered while building this repo -- kicad-cli as the fast headless
    check, always run it from a scratch cwd, the extends-symbol silent-fail
    bug, using existing files as format templates, not editing files while a
    GUI session has the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
2026-08-16 Add .gitattributes for cross-platform line-ending consistency; document Windows/Linux tool paths
    .gitattributes normalizes all KiCad/text files to LF on checkout, so a
    Windows contributor's git config can't silently introduce CRLF and cause
    noisy diffs/merge pain -- verified all tracked files were already
    consistently LF before adding this, nothing needed renormalizing.
    README: added Windows/Linux kicad-cli and pcbnew-python paths alongside
    the existing macOS ones (previously Mac-only), plus a short section
    confirming cross-platform compatibility was actually checked (no absolute
    Mac paths in any project/library file, no Windows-illegal filenames, no
    path-length concerns, consistent line en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
2026-08-16 Compile passives reference from each chip's real datasheet reference design
    New docs/passives-reference.md: per-chip table of every passive called for
    by that chip's own real reference/typical-application circuit (not
    guessed), cross-referencing what's already placed vs. what the datasheet
    actually shows.
    Found and fixed one real gap while doing this: Qorvo's own DWM3000
    'Example Application Circuit' (Figure 11) shows a 100k pulldown on
    IRQ/GPIO8 'to prevent spurious interrupts' -- missing from the design
    entirely until now. Added as R9 (wristband/radio_mcu.kicad_sch) and
    R25-R28, one per anchor (bay-station/uwb_anchors.kicad_sch).
    Also documented two nuances found by reading the same figu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
    [radio_mcu.kicad_sch, uwb_anchors.kicad_sch]
2026-08-16 Document DWM3000's antenna keep-out layout requirement
    Found while re-reading the DWM3000 datasheet for the passives compile --
    Section 6.1/Figure 10 requires a ~10mm no-metal keep-out zone around the
    antenna on the application board (flooding copper there degrades RF
    performance) on all 5 DWM3000 placements across both boards. Not
    actionable yet (neither board has started PCB layout), but flagged now in
    shared/README.md and docs/decisions.md so it isn't rediscovered later.
2026-09-19 Document the positioning scheme; add CLAUDE.md, firmware skeleton, cost model
    The repo described positioning only as "multilateration / TDoA-style" and
    treated the four bay-station anchors as symmetric peers. The actual scheme
    is a hybrid: the center anchor does two-way ranging for RANGE, and the three
    outer anchors take TDoA against it for DIRECTION. That asymmetry drives the
    clock architecture, so it needed writing down.
    New docs/positioning.md carries the scheme, the geometry, the error budget
    and the clock requirement it forces. Key figures, derived from real
    datasheets rather than estimated:
    - 1 ns of clock error = 30 cm of position error; at a 1 m baseline, 1 cm of
    differential pat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
2026-09-19 Wristband: consolidate onto one DWM3001C, delete the antenna sheet
    The tag's BLE radio turned out to serve no purpose -- it talks only over
    UWB. Once BLE is not a requirement the question stops being "which BLE
    module" and becomes "what is the simplest way to get a Cortex-M4 talking to
    a DW3110". That is one DWM3001C: DW3110 transceiver, nRF52833 MCU, LIS2DH12
    accelerometer, both antennas, power management and crystal in one part.
    Counterintuitively this is the simpler board. A discrete MCU would have
    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
    [antenna.kicad_sch, radio_mcu.kicad_sch, wristband.kicad_sch]
2026-09-19 Bay station: discrete DW3210 array on a shared clock, Nordic BT840 host
    Two coupled changes, both forced by the positioning scheme.
    UWB ARRAY. TDoA compares timestamps across receivers, so they must share a
    time base. The DWM3000 module makes that impossible -- its 24 pins contain
    no clock pin and its crystal is internal and unreachable, so four of them
    cannot be synchronised at any price. The bare DW3000 IC can: Datasheet v1.3
    Table 10 states a 38.4 MHz signal may be supplied from an external reference
    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
    [bay-station.kicad_sch, clock_dist.kicad_sch, connectivity.kicad_sch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]
2026-09-19 Add status LEDs and test points to both boards; update status docs
    Two gaps found by reviewing the repo against what the boards actually need.
    STATUS LEDS. The system had ZERO LEDs, while MCP73831's STAT and MCP73871's
    STAT1/STAT2/~PG all sat unconnected. No way to tell whether either board was
    powered, charging, charged or working -- a poor property for a device whose
    purpose is locating someone in trouble, and far cheaper to fix at schematic
    stage than after layout. New indicators.kicad_sch on each board: wristband
    D2 (charge) and D3 (system), bay station D4-D6 from the charger outputs plus
    D7 on a host GPIO.
    TEST POINTS. Also zero, on a design whose central difficulty is
    sub-nanosecond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
    [indicators.kicad_sch, testpoints.kicad_sch]
2026-09-19 Run ERC/DRC with KiCad 10.0.6: fix 71 off-grid pins, record results
    First verification pass with a real KiCad install. Everything before this was
    structurally checked only (paren balance, refdes uniqueness, sheet linkage).
    RESULT: zero errors on both boards. Wristband 104 violations, bay station
    452, all warnings, and overwhelmingly the documented placement-only state --
    pin_not_connected, power_pin_not_driven, pin_not_driven. Both boards' sheets
    loaded and every refdes appears in the reports, so none of the new
    hand-authored symbols triggered the extends-style silent load failure.
    FIXED: 71 endpoint_off_grid warnings (12 wristband, 59 bay station). Symbol
    instances had been placed at inte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
    [clock_dist.kicad_sch, connectivity.kicad_sch, indicators.kicad_sch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]
2026-09-21 Fix stale part references left behind by the architecture swap
    Review of #1 found schematic metadata still describing the parts this PR
    replaces. All edits are description/comment text -- no symbols, nets, values
    or footprints touched. Component counts unchanged (bay 84, wristband 38) and
    ERC is bit-identical: 452 / 104 violations, zero errors.
    programming_debug (both boards) -- the J3 description still gave NINA-B111's
    SWD pins. The bay-station copy was the dangerous one: it called pin 15
    "SWDIO", but on the BT840 pin 15 is SWDCLK and SWDIO is pin 16, so wiring
    from that text would have swapped the pair.
    bay station, BT840: SWDCLK 15, SWDIO 16, P0.18/RESET 14,
    GN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
    [indicators.kicad_sch, programming_debug.kicad_sch, regulation.kicad_sch]
2026-09-24 Accept KiCad 10.0.6's expanded default project settings on the bay station
    Opening bay-station.kicad_pro in KiCad 10.0.6 rewrites it with the full
    current default set. Committing that rather than reverting it, so it stops
    reappearing as a phantom diff for whoever opens the board next.
    Nothing here is a design change -- it is all defaults KiCad 8.0 did not
    write out:
    - Zone fill parameters (hatch geometry, thermal relief gap and spoke width,
    min island area, pad connection mode) where 8.0 stored only min_clearance.
    - DRC rule severities for checks that did not exist in 8.0: creepage,
    hole_to_hole, track_angle, track_segment_length, text_on_edge_cuts,
    mirrored/nonmirrored text, tuning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
2026-09-24 Georeference the bay station: GNSS, magnetometer, tilt sensor
    The station is deployed outdoors and moved between sites, and the UWB
    array only ever produced position RELATIVE to its own antenna frame --
    usable by an operator standing at it, useless as a coordinate to hand
    anyone else.
    Position alone would not have fixed that. A GNSS fix says where the
    station is, not which way it faces, and the array reports bearing
    relative to the frame -- so without heading you get a circle of possible
    tag locations, not a point. Hence three parts on the new gnss sheet:
    U9 u-blox MAX-M10S -- where the station is
    U10 ST LIS3MDL -- which way it faces
    U11 ST LIS2DH -- tilt compensation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
    [bay-station.kicad_sch, gnss.kicad_sch]
2026-09-24 Close the weatherproofing items: the bay station gets an enclosure
    Decided 2026-09-23. Ingress rating, weatherproofing the four UWB SMA
    entries and the GNSS antenna entry, and weather exposure of the rigid
    antenna frame are enclosure design, not board design, and are no longer
    tracked as open board items.
    Three things the enclosure does not close, kept Open rather than swept
    along with the rest:
    - **It has to pass RF.** The BT840's BLE antenna is printed on the module,
    so it is inside the box -- a metal enclosure would kill the link to the
    laptop, and no RF connector is placed to move the antenna outside. The
    four UWB antennas are already remote on coax and the GNSS antenna is
    exte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
2026-09-24 Give the bay station its real 4-layer stackup
    bay-station.kicad_pcb was an 86-line stub: KiCad's 2-layer default, board
    thickness 1.6 mm, nothing on it. That directly contradicted a decision the
    docs had been carrying as settled since the architecture swap -- DW3000
    Section 7.3 forces a controlled-impedance build of at least four layers,
    and the file said two.
    Set from DW3000 Datasheet v1.3, Section 7.3.2 Figure 35 "Recommended QFN
    Stack-up". Figure 35 is the right one because this board uses DW3210
    (QFN40); Figure 34 is the WLCSP variant and does not apply:
    F.Cu 35 um
    prepreg 254 um
    In1.Cu 35 um
    core 400 um
    In2.Cu 35 um
    prepreg 254 um
    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
    [bay-station.kicad_pcb]
2026-09-25 Georeference the bay station: GNSS, magnetometer, tilt, enclosure, 4-layer stackup (#4)
    * Accept KiCad 10.0.6's expanded default project settings on the bay station
    hole_to_hole,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
    [bay-station.kicad_pcb, bay-station.kicad_sch, gnss.kicad_sch]
2026-09-25 Give firmware a home in the repo: agent context, ignores, conventions (#3)
    Firmware stays in this repo rather than getting its own. The pin map, the
    message formats in firmware/common/, and the calibration table are shared
    between the boards and the code, and an agent reading one repo sees both
    halves at once.
    - firmware/CLAUDE.md: firmware-side agent rules, layered under the root
    file so schematic sessions don't pay for them. The load-bearing rule is
    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
2026-09-25 Land the wristband branch on main: DWM3001C wiring, TPS7A02 LDO, PCB (#5)
    Brings six months of `dwm3001c-migration` onto current `main` as one commit.
    A true rebase was attempted first and abandoned: the branch's own first
    commit is a NINA-B400 migration that commit five then throws away, so
    replaying it meant resolving 16 files of conflict for a design state nobody
    wants. Squashed to a single three-way merge instead -- 18 conflicts, one
    pass.
    Both sides had independently migrated the wristband to the DWM3001C, so this
    was not a fast-forward. Resolution, by ERC evidence rather than recency:
    main's wristband 104 violations, 93 errors
    branch's wristband 1 violation, 0 errors
    m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
    [mechanical.kicad_sch, power_bms.kicad_sch, programming_debug.kicad_sch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]
2026-09-28 Import the DW3210 filtering set from Qorvo's reference design
    43 components onto uwb_array.kicad_sch: full per-anchor decoupling, RF1 DC
    blocks, RF2 terminations and VDD2a ferrite beads. Placement only, matching
    the rest of this board. The sheet previously had 16 components and not one
    capacitor.
    All values come from the real Qorvo DW3000 Datasheet v1.1, Figure 32
    "DW3000 WLCSP Application Circuit" -- Qorvo's own reference design. Figure 32
    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
    [uwb_array.kicad_sch]
2026-09-28 Add the missing I2C pull-ups; audit the design for level shifters
    R37 (SDA), R38 (SCL), R39 (MAX17048 ALRT), all 2.2k to +3V3, on
    connectivity.kicad_sch. The bay station had ZERO I2C pull-ups while
    carrying three devices on the bus: MAX17048 (0x36), LIS3MDL (0x1C/0x1E),
    LIS2DH (0x18/0x19). I2C is open-drain and cannot return to a logic high
    without them, so this was a functional gap, not a refinement.
    power_bms_notes.md had already flagged this and deliberately deferred it,
    because the right pull-up rail is the host's logic supply and the host was
    then an unbuilt ESP32-S3. That reasoning was correct; the host is now the
    3.3 V BT840, so it is decidable. The pull-ups live on the host's sheet,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
    [connectivity.kicad_sch]
2026-09-29 Reject an external wristband IMU; flag that motion-gating may not be free
    Docs only. No schematic change, which is the point.
    An IMU was asked for on the wristband. Declined: the DWM3001C already
    contains an ST LIS2DH12 accelerometer, and a second one costs board area and
    standby current on the one board in this system that can least afford
    either. The tag is the power-constrained side -- the whole TDoA scheme is
    built around it transmitting once. This also upholds the standing rule in
    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
2026-09-29 Wire up power_bms, regulation and programming_debug; tie off floating grounds
    The bay station was built entirely from global labels and power symbols --
    zero drawn wires on any sheet. This starts converting the power path to
    explicit wiring and connects the grounds that were left floating:
    - power_bms: 62 wires; 31 label justifications flipped left->right where
    the labels were mirrored. No symbols added or removed.
    - regulation: 11 wires, 3 junctions, 5 GND symbols (#PWR01-05).
    - programming_debug: 2 wires, 1 junction, 1 GND symbol (#PWR06).
    ERC goes 518 -> 497 violations (494 -> 473 errors), entirely in
    pin_not_connected (360 -> 342), power_pin_not_driven (98 -> 96) and
    pin_not_driven (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
    [bay-station.kicad_sch, clock_dist.kicad_sch, connectivity.kicad_sch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]
2026-11-06 Add a Design Specifications quick-reference to the README
    Pulls the resolved numbers (accuracy target, RF/clock specs, positioning
    architecture, power budgets, cost, toolchain) into one at-a-glance section
    instead of leaving them scattered across docs/positioning.md,
    docs/decisions.md, and docs/bom-cost.md. Points to those files for full
    reasoning and citations rather than duplicating them.
2026-11-06 Sync README status with current ERC/DRC/git state; log in-flight PRs
    Root README and bay-station/README.md both had drifted from reality:
    - Bay station Regulation and Programming/Debug sheets have partial wiring
    from the 2026-09-29 wiring pass (cb20b06), not "placement only, not wired".
    - bay-station/README.md's ERC summary said "518 violations, ZERO errors" --
    wrong even before this session (473 of 494 violations were already
    error-severity). Replaced with a dated, re-verified count (497 violations,
    473 errors, kicad-cli 10.0.5, 2026-11-06) and an explicit correction.
    - "kicad-cli sch export netlist returns zero nets" is now also stale: 372
    nets exist, 341 still single-pin placeh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
2026-11-06 Pre-port PR #9's R37-R39 I2C pull-ups onto the reformatted connectivity.kicad_sch
    PR #9 (fix/i2c-pullups) was written against the pre-wiring-pass (KiCad 8.0
    format) connectivity.kicad_sch, which the power-wiring merge reserialized to
    10.0 format -- a textually unrelated file, so the PR conflicts on every hunk
    even though the actual content (3 placement-only 2.2k pull-ups, R37/R38/R39,
    with their full datasheet-derived justification) is unchanged.
    Hand-ported rather than text-merged: added the missing Device:R lib_symbol
    cache block (copied from power_bms.kicad_sch, already in 10.0 format) and
    rebuilt the three resistor instances using an existing 10.0-format resistor
    instance as the structu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
2026-11-06 Pre-port PR #8's 43-component DW3210 decoupling set onto the reformatted uwb_array.kicad_sch
    Same situation as b7ab51f: PR #8 (feat/uwb-decoupling) was written against
    the pre-wiring-pass (KiCad 8.0 format) uwb_array.kicad_sch, which 66d53fa
    reserialized to 10.0 format. Hand-ported rather than text-merged:
    - Added the Device:FerriteBead lib_symbol cache block (for FB1-FB4, the
    BLM03PG330SN1D per-anchor ferrite beads) -- this one was already
    10.0-shaped in the source branch, copied near-verbatim.
    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
2026-11-06 Add per-anchor CS/IRQ test points; put component Value on real silkscreen for every part
    Test points (bay station): the shared SPI bus alone doesn't show which
    anchor is being addressed, and only A0's IRQ was probed. Added TP15-TP18
    (CS_A0-CS_A3) and TP19-TP21 (IRQ_A1-IRQ_A3) to testpoints.kicad_sch, same
    placement-only convention as the existing 14 points -- bay station is now
    at 21. Verified: balanced parens, all 21 references unique, grid-aligned
    (first attempt wasn't -- fixed after kicad-cli flagged endpoint_off_grid),
    and ERC shows exactly +7 (one new unconnected pin per test point).
    Silkscreen: moved every footprint's Value property to F.SilkS, visible, on
    both the convention (going f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
